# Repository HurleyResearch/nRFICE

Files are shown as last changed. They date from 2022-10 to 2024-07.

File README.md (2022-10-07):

# nRFICE
### nRF5340 with ICE40UP5K including JLink OB for instant BLE and FPGA development with zero dongles
In order to develop a number of comercial products, we (here at Hurley Research in Santa Cruz CA) needed a simple bluetooth 5 plus FPGA platform. nRFICE is meant to be a maximally simple solution for launching projects that require MCU plus FPGA and certainly if Bluetooth including mesh is needed.
### Arduino Uno compatibility
nRFICE is physically compatible with Arduino Uno shields, but take care that the GPIO level is 3.3V.
### JLink OB
Comercial eval/dev boards from chip manufactures, such as Nordic Semi, typically have the JLink debugger hardware embedded on the board for convenience. We have included JLink OB on nRFICE, allowing developers to get started without any additional hardare, programming dongles, etc. Out of box demos for both nRF5340 and ICE40UP5K can be loaded and debugged immediately with a single usb cable, or over BLE with the nRFICE android app.

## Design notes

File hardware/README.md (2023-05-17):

# nRFICE Hardware
Everything about the nRFICE PCB
- Eagle design files
- Gerbers
- Schematic
- Bill of matrials
- Pinout diagram

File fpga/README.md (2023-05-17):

# nRFICE Verilog Source
The nRFICE verilog source project is a simple RGB LED controller using PWM
- Bare bones hello world project for ICE40UP5K
- Built in Lattice Radiant IDE
## Getting started documentation will go here

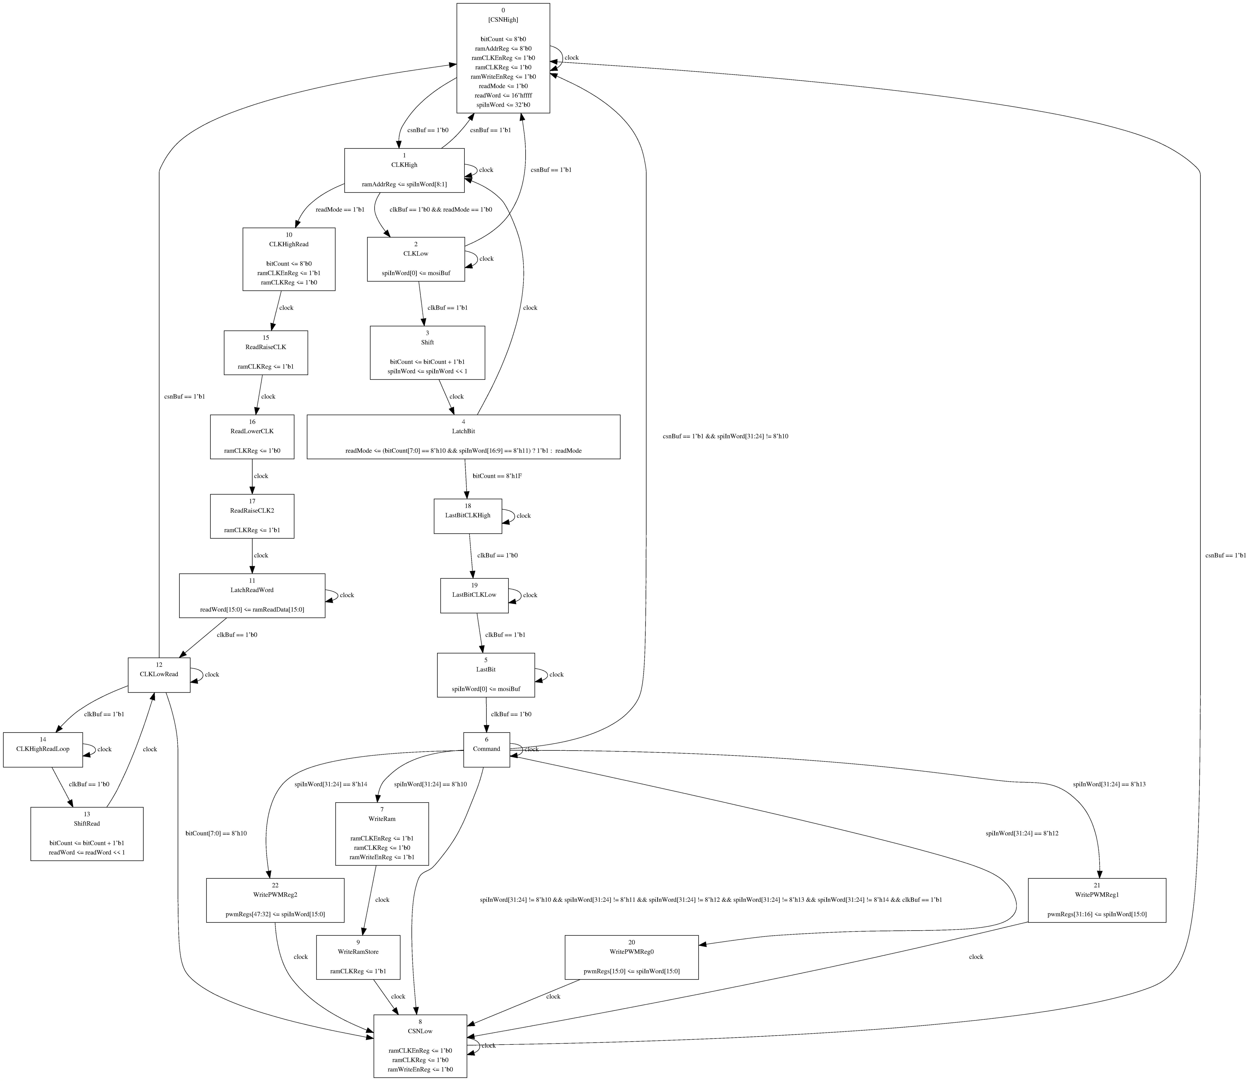
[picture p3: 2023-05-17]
fpga/work/spi.png

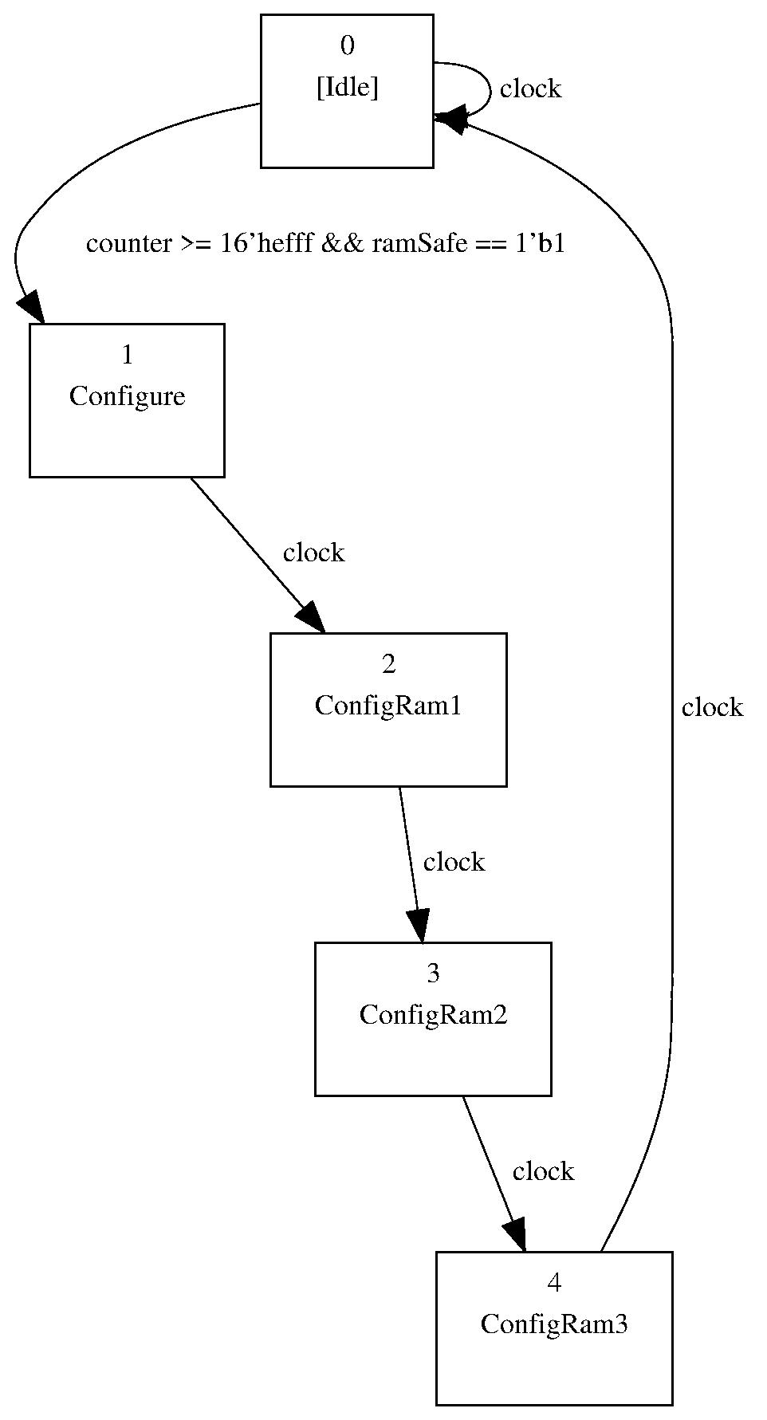
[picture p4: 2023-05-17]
fpga/work/pwm.png

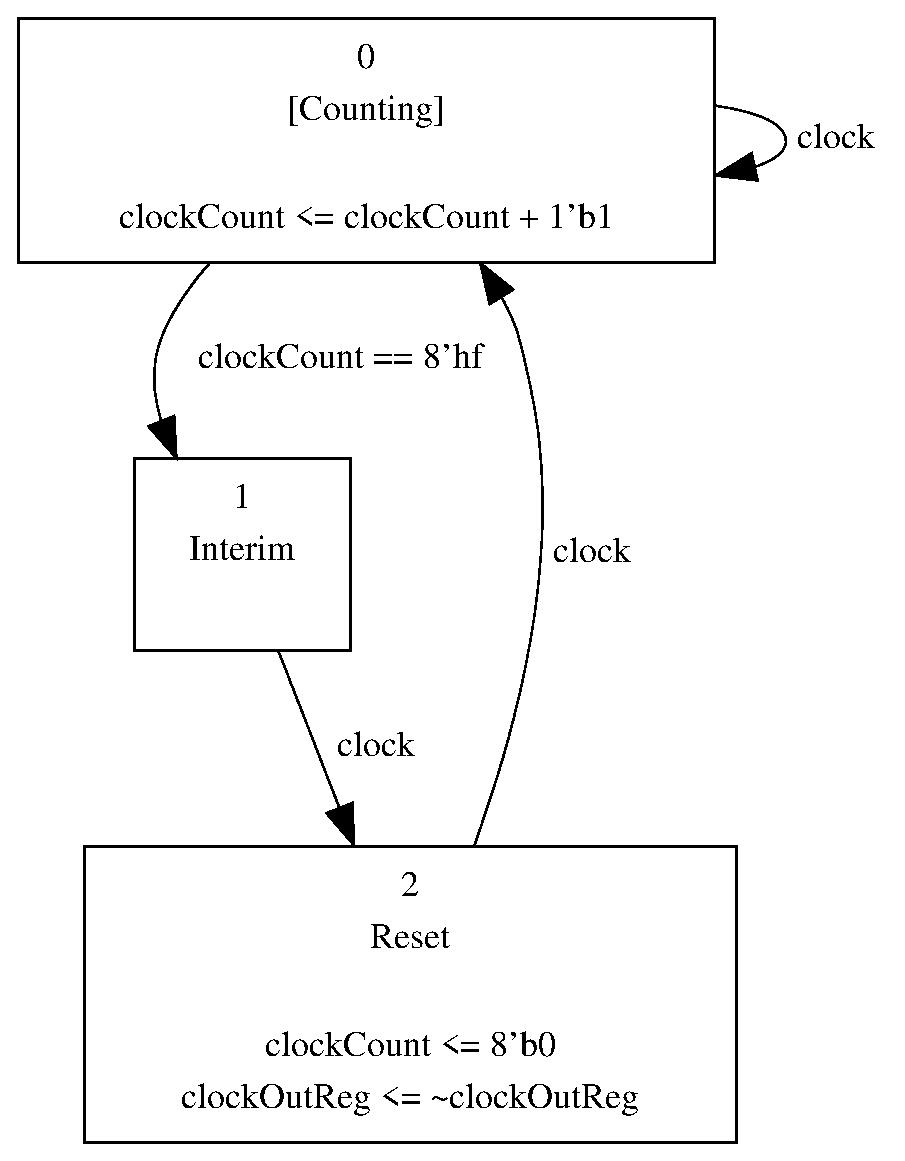
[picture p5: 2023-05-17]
fpga/work/clockstretch.png

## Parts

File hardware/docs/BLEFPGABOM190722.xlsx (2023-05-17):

Manufacturer | Manufacturer Part Number | Designator | Quantity | Description | Case | SMD BGA LLC(QFN) TH | Top/Bottom | points | Total points
BOOMELE | C30734 | J16, J9 | 2 | 2x8 pos 2.54mm female header | C30734 | TH | Top | 16 | 32
Adesto Technologies | AT25SF128A-SHB-T | U10 | 1 | NOR Flash 128 Mbit,2.7V to 3.6V,SOIC-W 208mil | AT25SF128A-SHB-T | SMD | Top | 8 | 8
BOOMELE | C40877 | J11 | 1 | 1x6 pos 2.54 female header | C40877 | TH | Top | 6 | 6
YAGEO | RC0402FR-075K1L | R19, R20, R21, R25 | 4 | 5.1K,1%,1/16W,0402 | RCL_R0402 | SMD | Top | 2 | 8
MICRONE | ME6211A33M3G-N | U3 | 1 | 500mA 3.3V SOT-23-3 LDO | ME6211A33M3G-N | SMD | Top | 3 | 3
MICRONE | ME6206A25XG | U6 | 1 | 300mA 2.5V SOT-23 LDO | ME6206A25XG | SMD | Top | 3 | 3
Samsung | CL05A105KP5NNNC | C11, C14, C15, C16, C17, C18, C19, C20, C21, C23, C5, C68, C71 | 13 | 1uF,10V,10%,X5R,0402 | RCL_C0402 | SMD | Top | 2 | 26
YAGEO | RC0402FR-07100RL | R22, R8, R91 | 3 | 100 Ohm,1%,1/16W,0402 | RCL_R0402 | SMD | Top | 2 | 6
YAGEO | RC0402FR-07220RL | R11 | 1 | 220 Ohm,1%,1/16W,0402 | RCL_R0402 | SMD | Top | 2 | 2
YAGEO | RC0402FR-070RL | R24, R38, R39 | 3 | 0 Ohm,1%,1/16W,0402 | RCL_R0402 | SMD | Top | 2 | 6
Murata | BLM15AG121SN1D | L1 | 1 | FERRITE BEAD 120 OHM 0402 1LN | L0402 | SMD | Top | 2 | 2
ST Micro | STM32F072CBU6TR | U8 | 1 | JLINK OB MCU | STM32F072CBU6TR | SMD | Top | 49 | 49
XFCN | PZ254V-11-04P | J14, J15, J17, J3 | 4 | 1x4 pos 2.54 male header | PZ254V-11-04P | TH | Top | 4 | 16
BOOMELE | C35445 | J5 | 1 | 1x10 pos 2.54 female header | C35445 | TH | Top | 10 | 10
Fanstel | BT40F | U2 | 1 | nRF5340 Module | BT40F | SMD | Top | 61 | 61
YAGEO | RC0402FR-07100KL | R17 | 1 | 100K Ohm,1%,1/16W,0402 | RCL_R0402 | SMD | Top | 2 | 2
YAGEO | RC0402FR-07470RL | R10 | 1 | 470 Ohm,1%,1/16W,0402 | RCL_R0402 | SMD | Top | 2 | 2
YAGEO | RC0402FR-0710KL | R13, R14, R15, R18, R26, R27, R28, R29, R30, R31, R32, R37, R9 | 13 | 10K Ohm,1%,1/16W,0402 | RCL_R0402 | SMD | Top | 2 | 26
HX | HX6306P122MR | U9 | 1 | 300mA 1.2V SOT-23 LDO | HX6306P122MR | SMD | Top | 3 | 3
HGSEMI | LM1085S-5.0 | U4 | 1 | 3A 5V TO-263-3 LDO | LM1085S-5.0 | SMD | Top | 4 | 4
Yuandi | TS-1091C-A8B3-D2 | S1, S6, S7, S8 | 4 | 4.5mm 7mm SMD Tactile Switch | TS-1091C-A8B3-D2 | SMD | Top | 3 | 12
Samsung | CL21A106KOQNNNE | C12, C13, C3, C4, C9 | 5 | 10uF,16V,10%,X5R,0805 | RCL_C0805 | SMD | Top | 2 | 10
YAGEO | RC0402FR-071KL | R1, R5 | 2 | 1K Ohm,1%,1/16W,0402 | RCL_R0402 | SMD | Top | 2 | 4
SAKRO | DC-050-2.0-B | J7 | 1 | DC Power Receptacle 2mm 6.4mm 2A 30V SMD | DC-050-2.0-B | SMD | Top | 4 | 4
KEMET | C0402C104K8RAC7867 | C32, C34, C48, C6, C62, C63, C65, C67, C7, C70, C75, C8 | 12 | 0.1uF,10V,10%,X7R,0402 | RCL_C0402 | SMD | Top | 2 | 24
BOOMELE | C57369 | J4 | 1 | 1x10 pos 2.54 male header | C57369 | TH | Top | 10 | 10
YAGEO | RC0402FR-07680RL | R2, R3, R6, R7 | 4 | 680 Ohms,1%,1/16W,0402 | RCL_R0402 | SMD | Top | 2 | 8
Samsung | CL21A226MAYNNNE | C22 | 1 | 22uF,25V,20%,X5R,0805 | RCL_C0805 | SMD | Top | 2 | 2
XINGLIGHT | XL-1608SYGC-06 | D5 | 1 | 25mA 38mcd 2.1V 2800K~3160K 575nm 120° 55mW 0603 LED | XL-1608SYGC-06 | SMD | Top | 2 | 2
Nexperia | PRTR5V0U2X | D2 | 1 | TVS DIODE 5.5VWM SOT143B | PRTR5V0U2X | SMD | Top | 4 | 4
DEALON | USB-TYPE-C-020 | J2, J8 | 2 | usb type c connector | USB-TYPE-C-020 | SMD | Top | 12 | 24
CreeLED | UHD1110-FKA-CL1A13R3Q1BBQFMF3 | U1, U5 | 2 | RGB LED 1.9V Red, 2.9V Green, 2.9V Blue 0404 | UHD1110-FKA | SMD | Top | 4 | 8
YAGEO | RC0603FR-071RL | R16, R34, R35, R36 | 4 | 1 Ohm,1%,1/10W,0603 | RCL_R0603 | SMD | Top | 2 | 8
KEMET | C0402C103J4RAC | C10, C31, C69 | 3 | 0.01uF,16V,5%,X7R,0402 | RCL_C0402 | SMD | Top | 2 | 6
Lattice | ICE40UP5K-SG48I | U7 | 1 | FPGA 48-VFQFN | ICE40UP5K-SG48I | SMD | Top | 48 | 48
YAGEO | RC0603FR-070RL | R12, R33 | 2 | 0 Ohm,1%,1/10W,0603 | RCL_R0603 | SMD | Top | 2 | 4
Epson | X1G004171004000 | OSC1 | 1 | 32MHz Oscillator | X1G004171004000 | SMD | Top | 4 | 4

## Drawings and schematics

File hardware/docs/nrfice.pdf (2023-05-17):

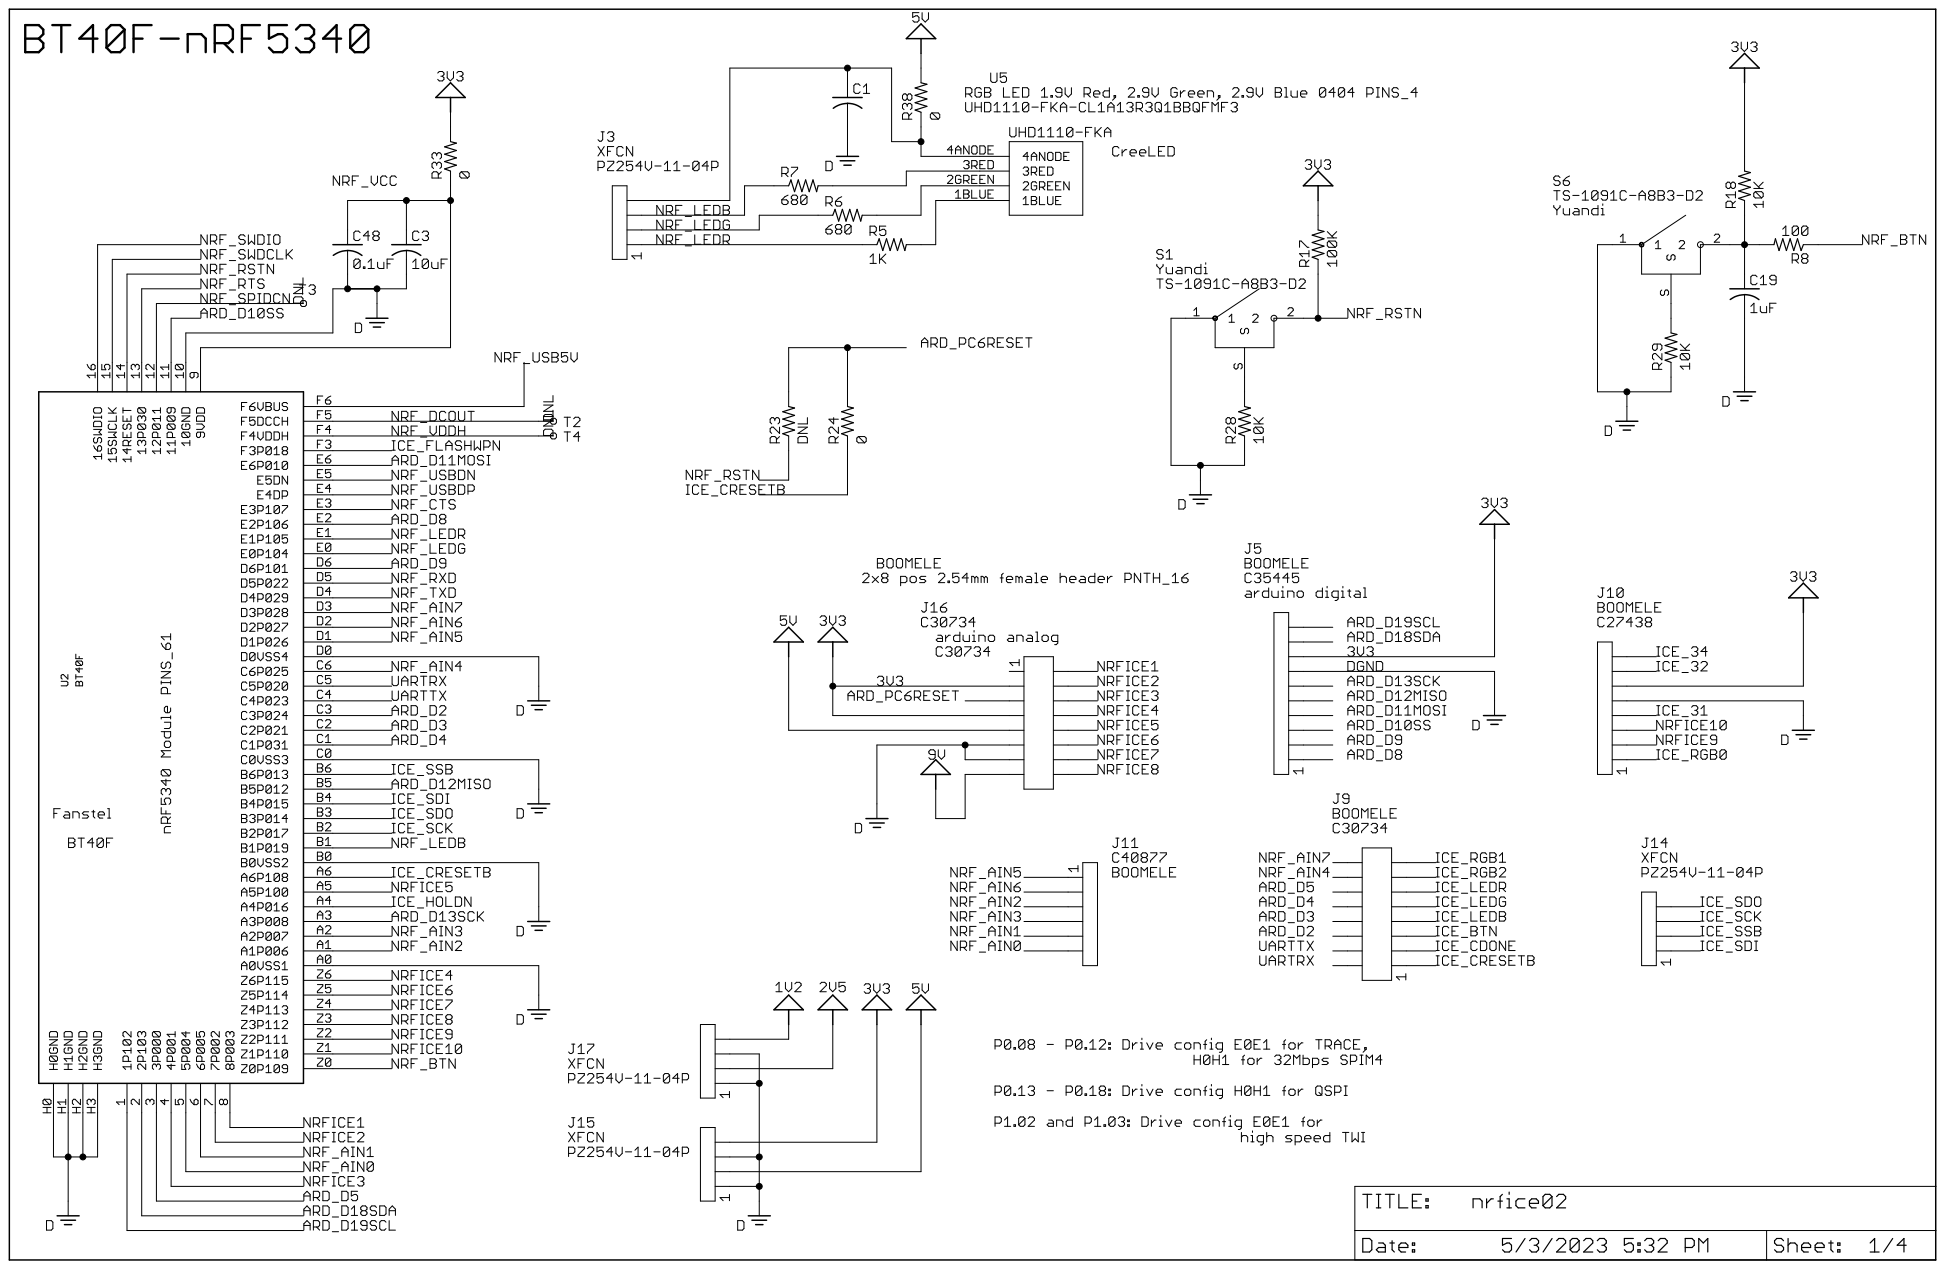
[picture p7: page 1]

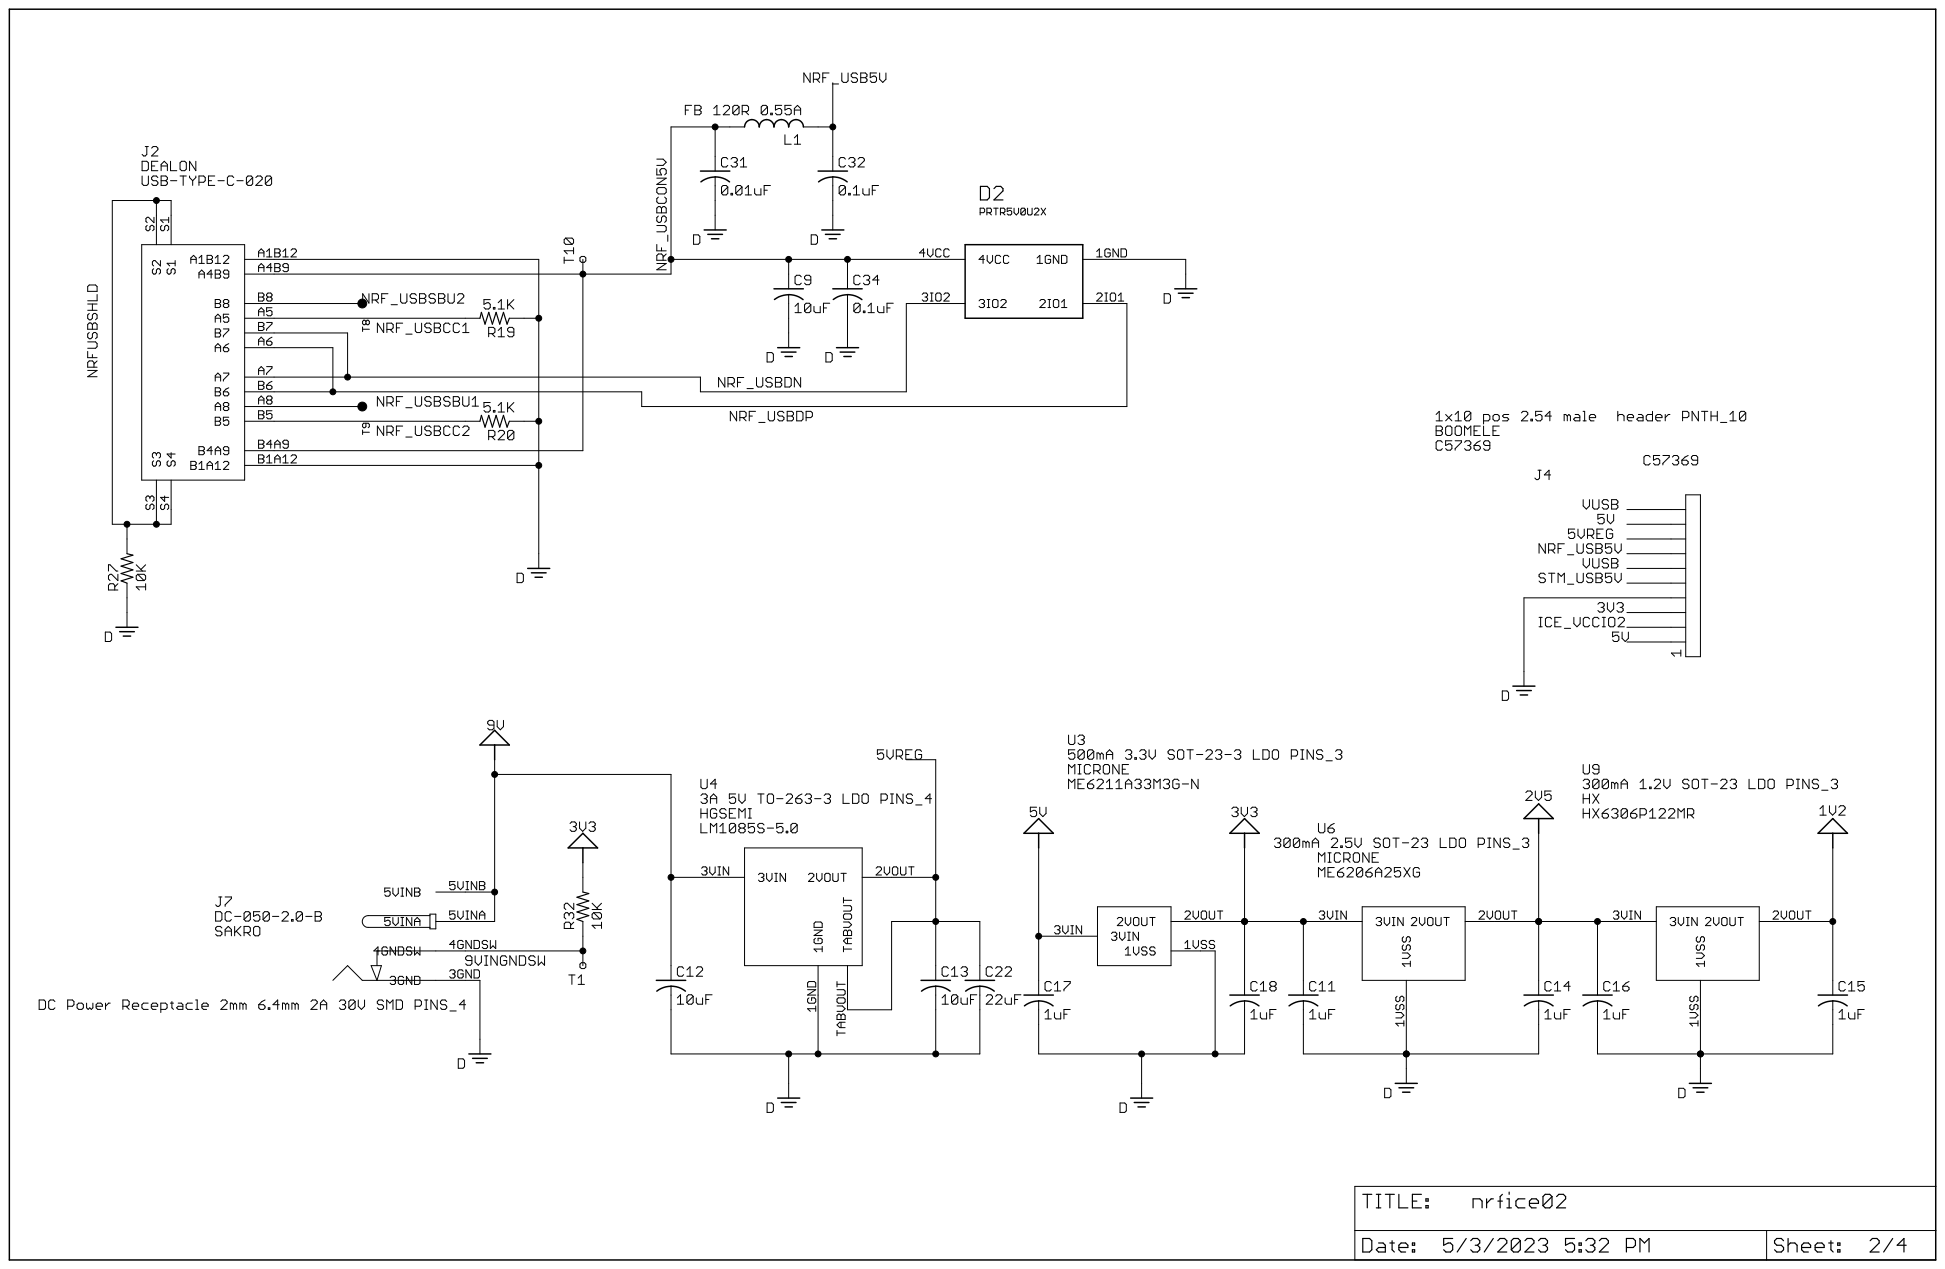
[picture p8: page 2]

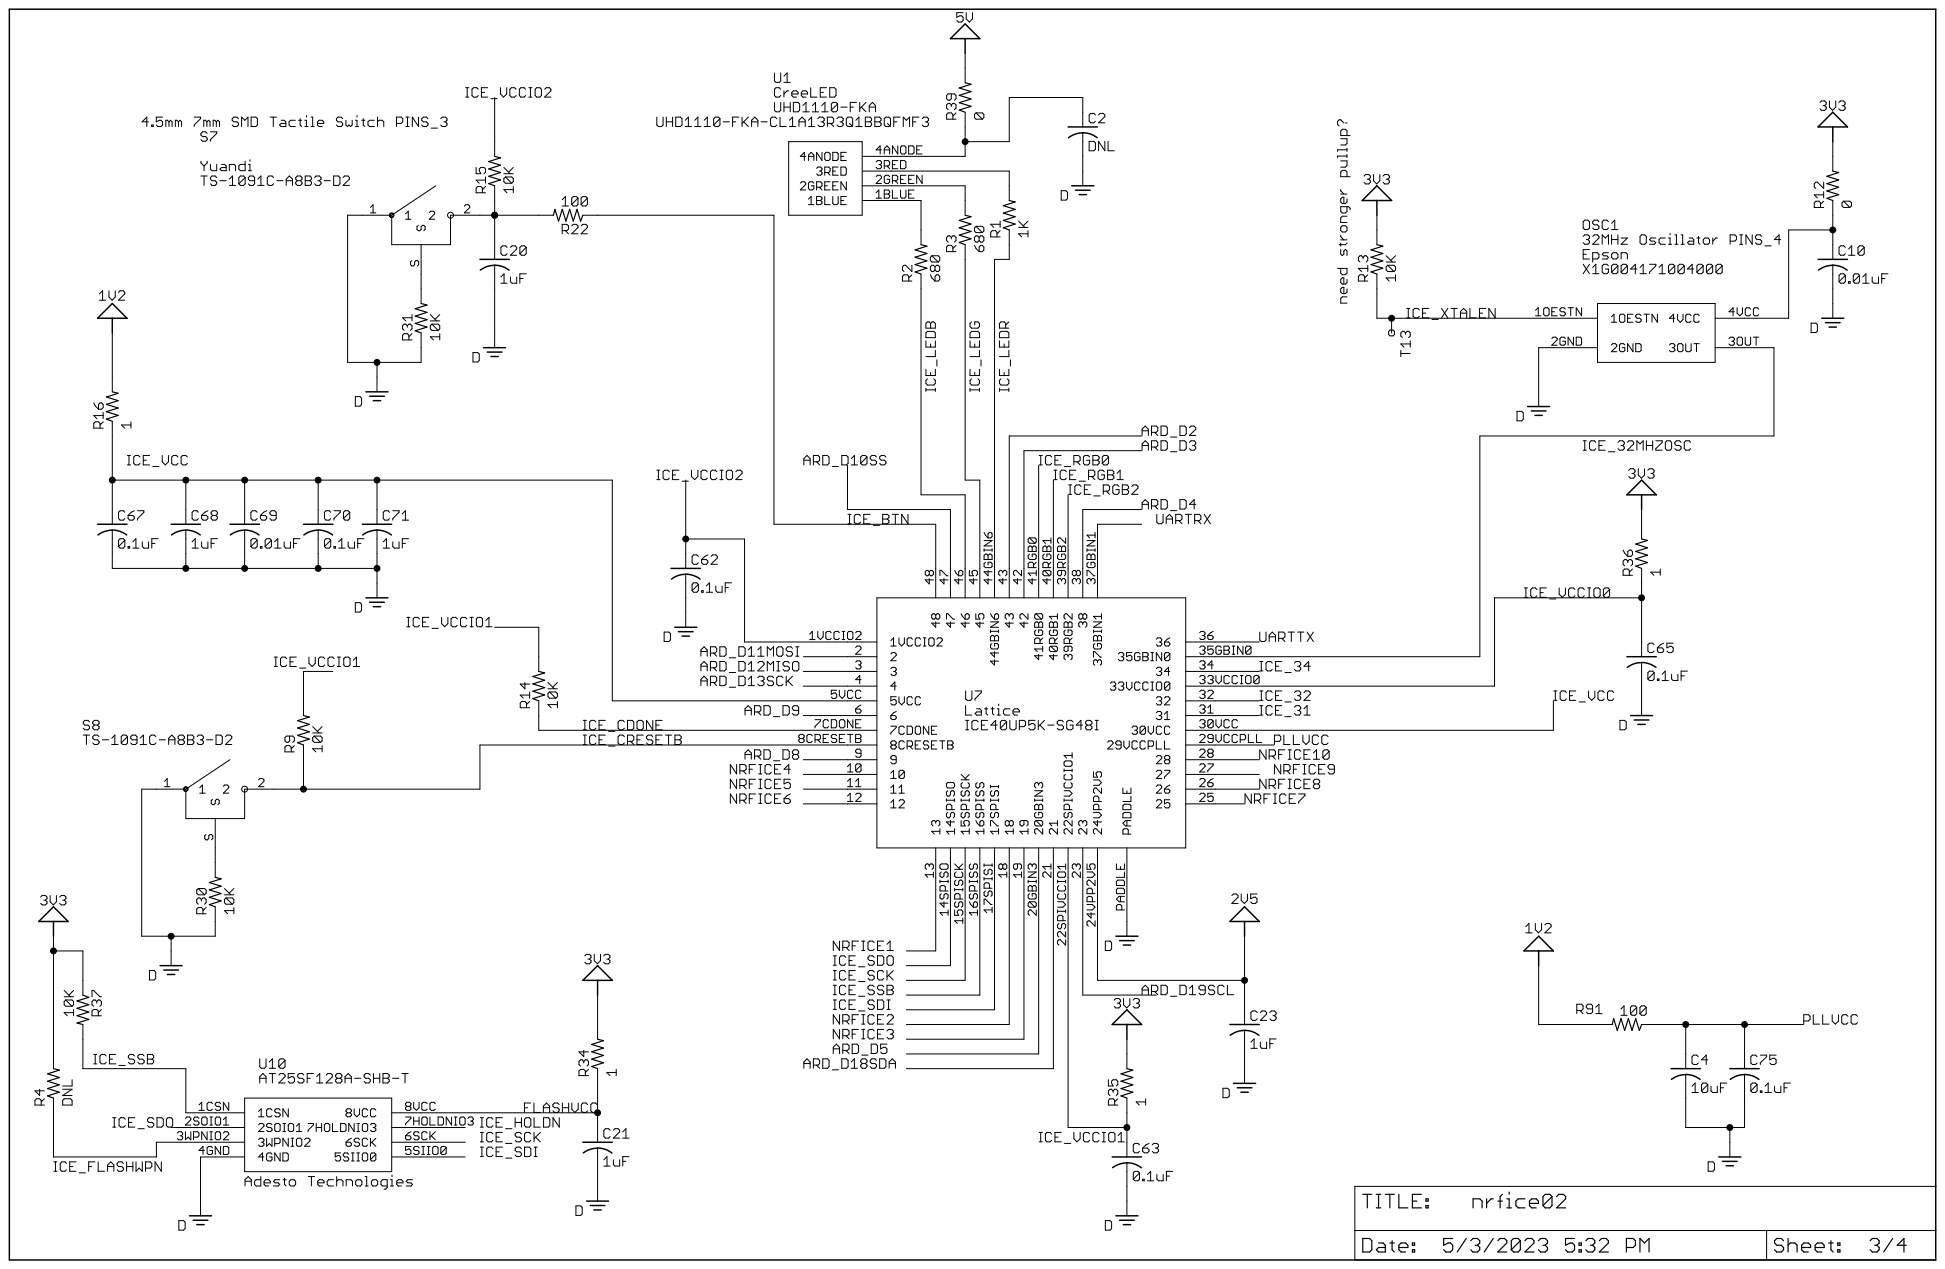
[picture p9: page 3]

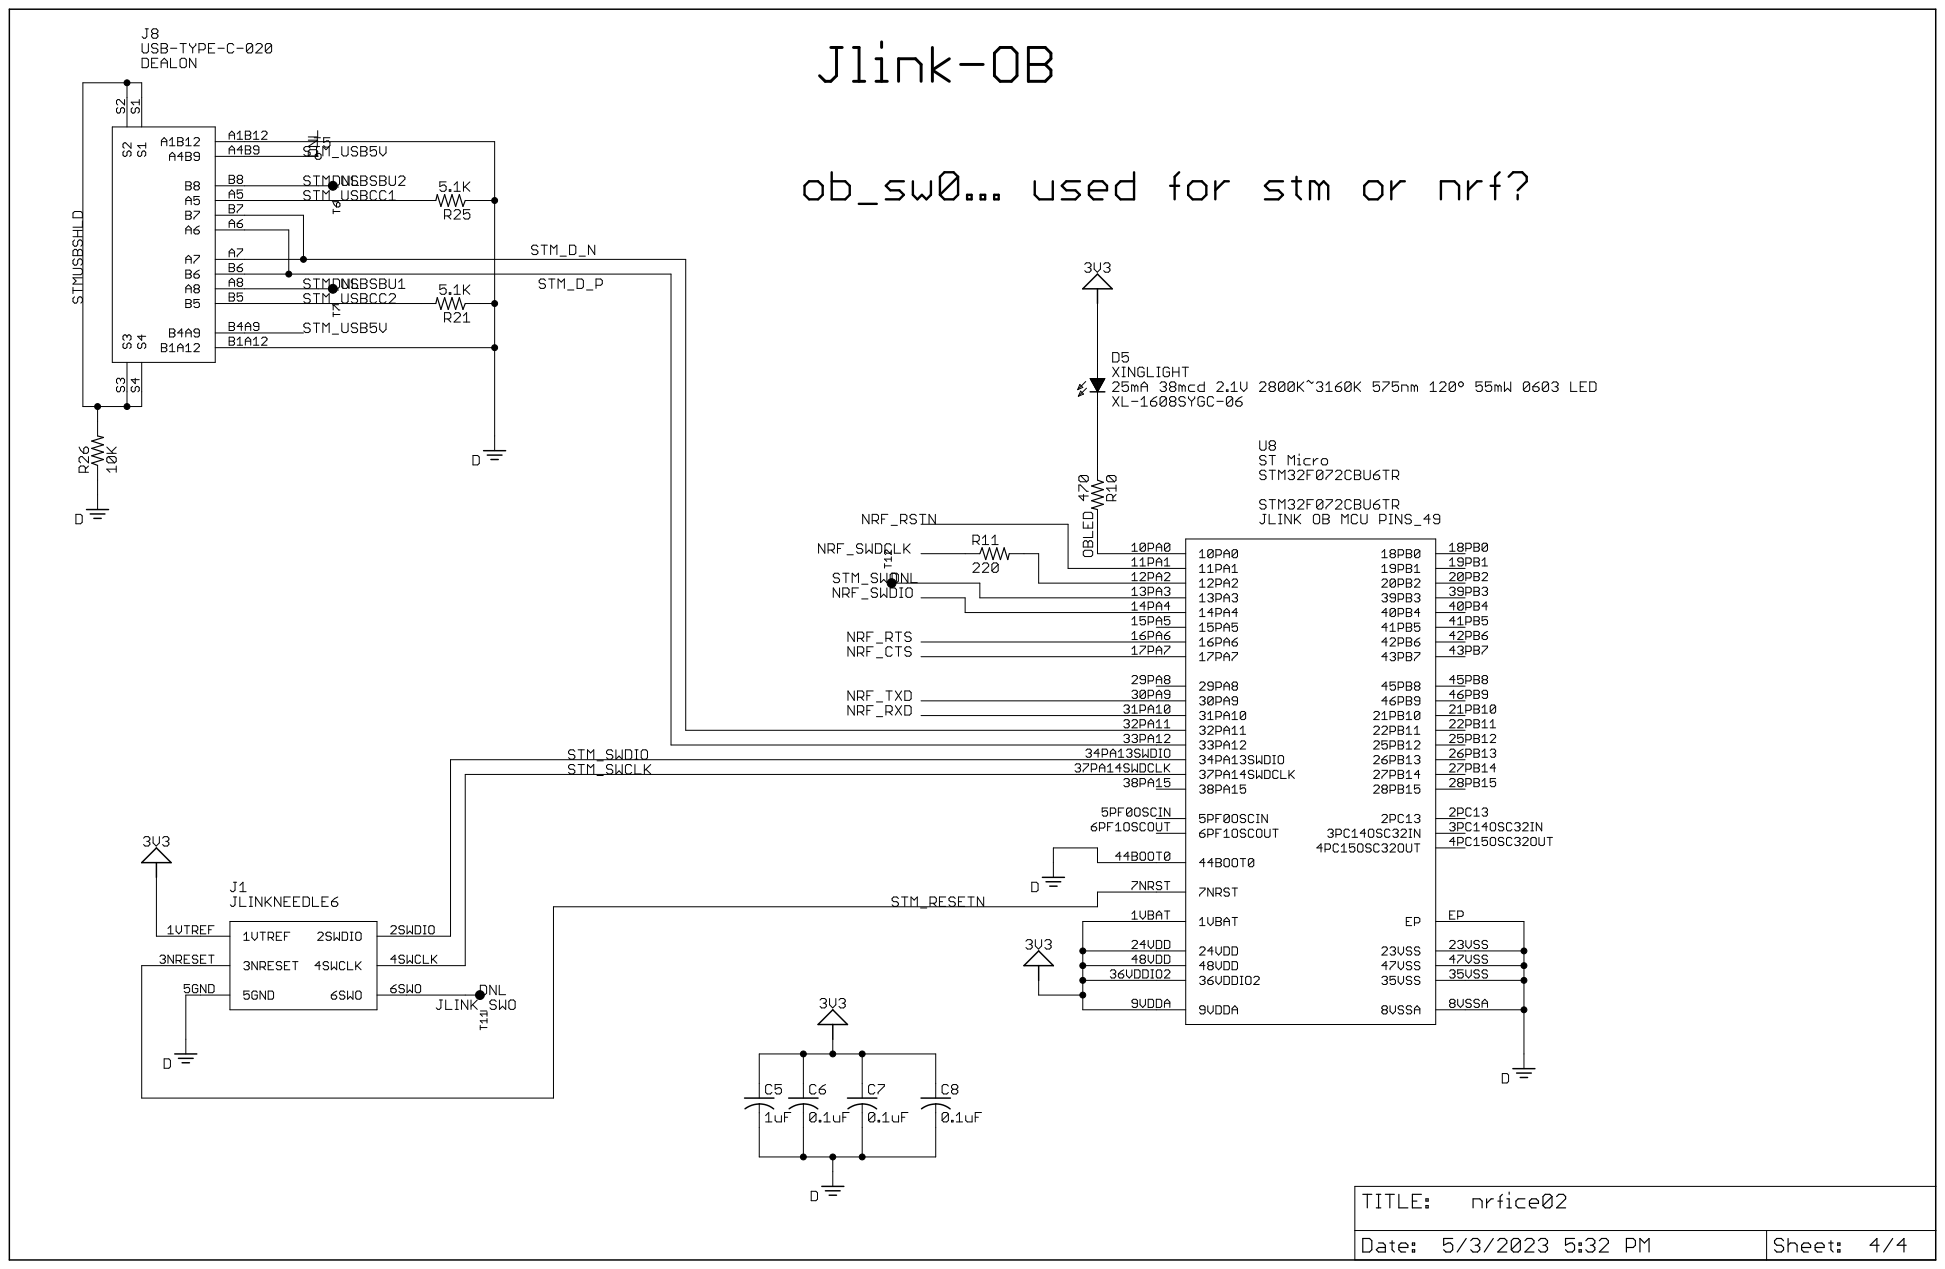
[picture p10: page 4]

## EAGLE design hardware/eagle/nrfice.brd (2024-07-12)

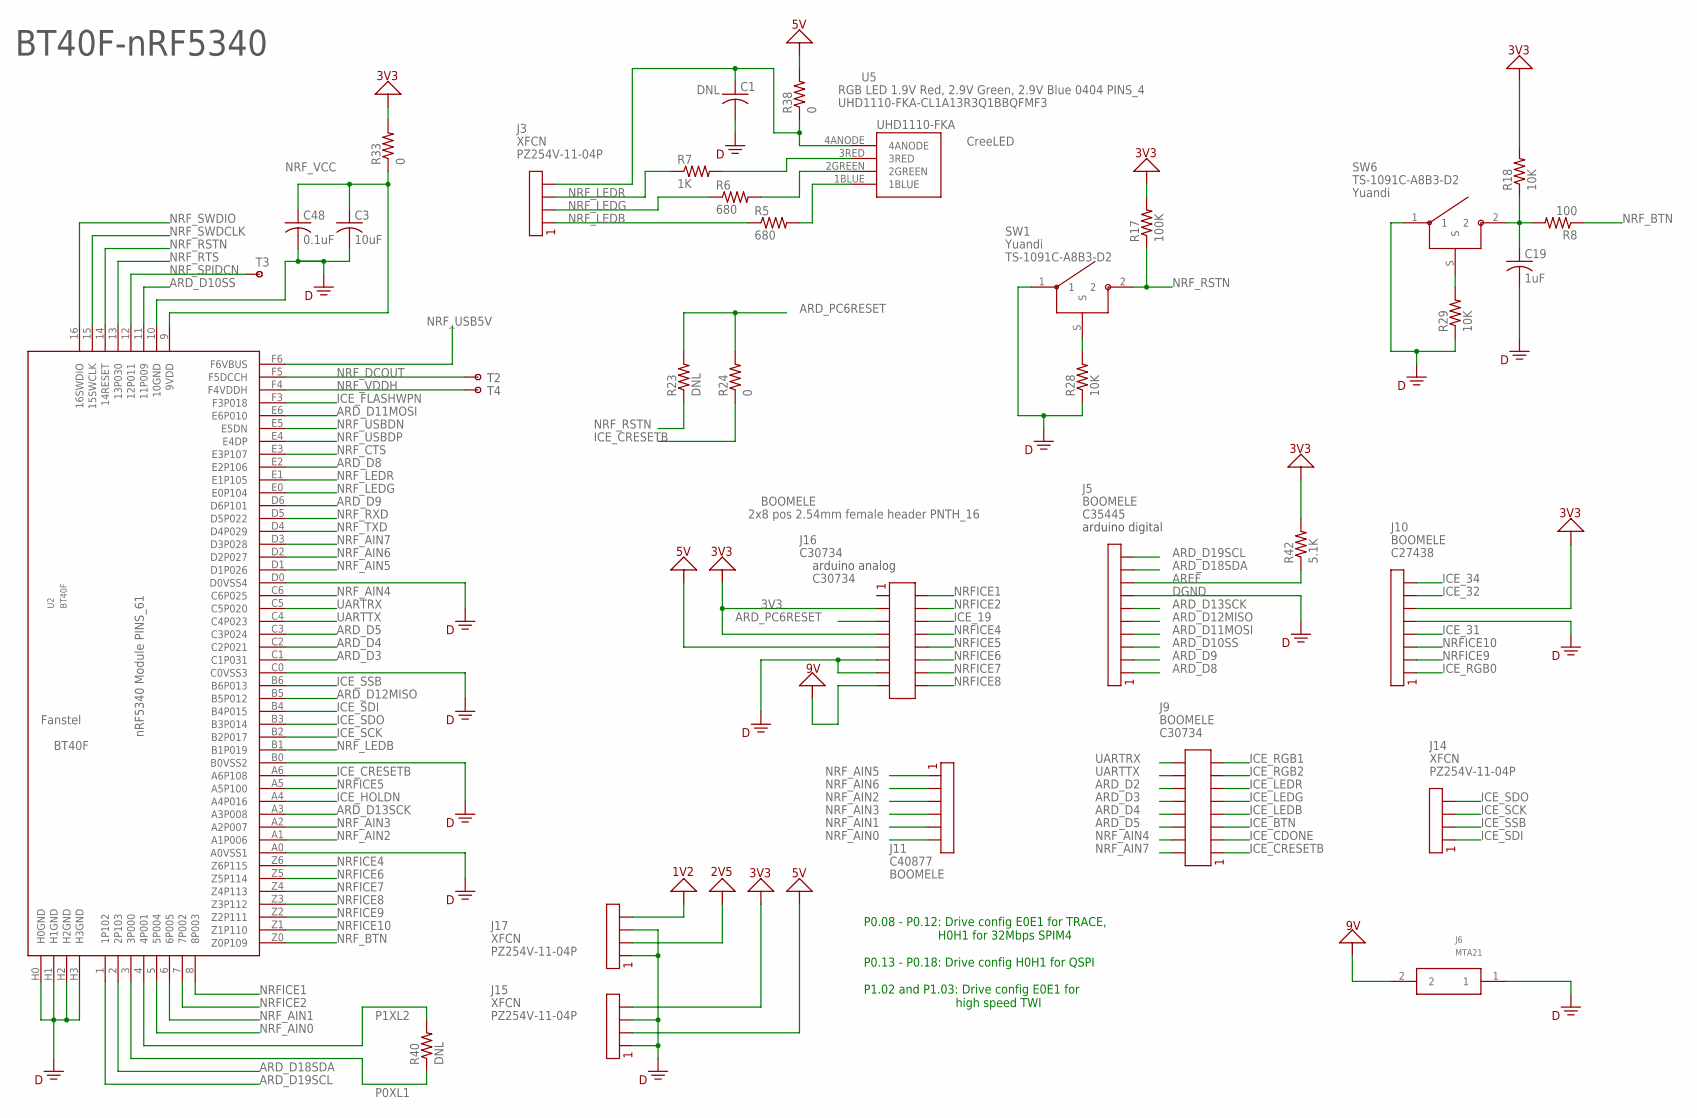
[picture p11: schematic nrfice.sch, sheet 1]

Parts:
C1: DNL; RCL_C0402; MPN CL05A105KP5NNNC
C3: 10uF; RCL_C0805; MPN CL21A106KOQNNNE
C19: 1uF; RCL_C0402; MPN CL05A105KP5NNNC
C48: 0.1uF; RCL_C0402; MPN C0402C104K8RAC7867
J3, J14, J15, J17: PZ254V-11-04P; MPN PZ254V-11-04P
J5: C35445; MPN C35445
J6: MTA21
J9, J16: C30734; MPN C30734
J10: C27438; MPN C27438
J11: C40877; MPN C40877
R5, R6: 680; RCL_R0402; MPN RC0402FR-07680RL
R7: 1K; RCL_R0402; MPN RC0402FR-071KL
R8: 100; RCL_R0402; MPN RC0402FR-07100RL
R17: 100K; RCL_R0402; MPN RC0402FR-07100KL
R18, R28, R29: 10K; RCL_R0402; MPN RC0402FR-0710KL
R23, R40: DNL; RCL_R0402; MPN RC0402FR-0710KL
R24, R38: 0; RCL_R0402; MPN RC0402FR-070RL
R33: 0; RCL_R0603; MPN RC0603FR-070RL
R42: 5.1K; RCL_R0402; MPN RC0402FR-075K1L
SW1, SW6: TS-1091C-A8B3-D2; MPN TS-1091C-A8B3-D2
T2, T3, T4: MTA1
U2: BT40F; MPN BT40F
U5: UHD1110-FKA; MPN UHD1110-FKA-CL1A13R3Q1BBQFMF3

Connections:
1V2: J17.4; also elsewhere on the board
2V5: J17.2; also elsewhere on the board
3V3: J10.6, J15.4, J16.3, J16.7, R17.2, R18.2, R33.2, R42.2; also elsewhere on the board
5V: J15.2, J16.9, R38.2; also elsewhere on the board
9V: J6.2, J16.15; also elsewhere on the board
ARD_D2: J9.12; also elsewhere on the board
ARD_D3: J9.10, U2.C1 (C1P031); also elsewhere on the board
ARD_D4: J9.8, U2.C2 (C2P021); also elsewhere on the board
ARD_D5: J9.6, U2.C3 (C3P024); also elsewhere on the board
ARD_D8: J5.1, U2.E2 (E2P106); also elsewhere on the board
ARD_D9: J5.2, U2.D6 (D6P101); also elsewhere on the board
ARD_D10SS: J5.3, U2.11 (11P009); also elsewhere on the board
ARD_D11MOSI: J5.4, U2.E6 (E6P010); also elsewhere on the board
ARD_D12MISO: J5.5, U2.B5 (B5P012); also elsewhere on the board
ARD_D13SCK: J5.6, U2.A3 (A3P008); also elsewhere on the board
ARD_D18SDA: J5.9, U2.2 (2P103); also elsewhere on the board
ARD_D19SCL: J5.10, U2.1 (1P102); also elsewhere on the board
ARD_PC6RESET: J16.5, R23.2, R24.2
AREF: J5.8, R42.1
DGND: C1.2, C3.2, C19.2, C48.2, J5.7, J6.1, J10.5, J15.1, J15.3, J16.11, J16.13, J17.1, J17.3, R28.1, R29.1, SW1.1, SW6.1, U2.10 (10GND), U2.A0 (A0VSS1), U2.B0 (B0VSS2), U2.C0 (C0VSS3), U2.D0 (D0VSS4), U2.H0 (H0GND), U2.H1 (H1GND), U2.H2 (H2GND), U2.H3 (H3GND); also elsewhere on the board
ICE_19: J16.6; also elsewhere on the board
ICE_31: J10.4; also elsewhere on the board
ICE_32: J10.7; also elsewhere on the board
ICE_34: J10.8; also elsewhere on the board
ICE_BTN: J9.5; also elsewhere on the board
ICE_CDONE: J9.3; also elsewhere on the board
ICE_CRESETB: J9.1, R24.1, U2.A6 (A6P108); also elsewhere on the board
ICE_FLASHWPN: U2.F3 (F3P018); also elsewhere on the board
ICE_HOLDN: U2.A4 (A4P016); also elsewhere on the board
ICE_LEDB: J9.7; also elsewhere on the board
ICE_LEDG: J9.9; also elsewhere on the board
ICE_LEDR: J9.11; also elsewhere on the board
ICE_RGB0: J10.1; also elsewhere on the board
ICE_RGB1: J9.15; also elsewhere on the board
ICE_RGB2: J9.13; also elsewhere on the board
ICE_SCK: J14.3, U2.B2 (B2P017); also elsewhere on the board
ICE_SDI: J14.1, U2.B4 (B4P015); also elsewhere on the board
ICE_SDO: J14.4, U2.B3 (B3P014); also elsewhere on the board
ICE_SSB: J14.2, U2.B6 (B6P013); also elsewhere on the board
unnamed: R5.2, U5.1BLUE
unnamed: R6.2, U5.2GREEN
unnamed: R7.2, U5.3RED
unnamed: C19.1, R8.2, R18.1, SW6.2
unnamed: R28.2, SW1.S
unnamed: R29.2, SW6.S
unnamed: C1.1, J3.4, R38.1, U5.4ANODE
NRFICE1: J16.2, U2.8 (8P003); also elsewhere on the board
NRFICE2: J16.4, U2.7 (7P002); also elsewhere on the board
NRFICE4: J16.8, U2.Z6 (Z6P115); also elsewhere on the board
NRFICE5: J16.10, U2.A5 (A5P100); also elsewhere on the board
NRFICE6: J16.12, U2.Z5 (Z5P114); also elsewhere on the board
NRFICE7: J16.14, U2.Z4 (Z4P113); also elsewhere on the board
NRFICE8: J16.16, U2.Z3 (Z3P112); also elsewhere on the board
NRFICE9: J10.2, U2.Z2 (Z2P111); also elsewhere on the board
NRFICE10: J10.3, U2.Z1 (Z1P110); also elsewhere on the board
NRF_AIN0: J11.6, U2.5 (5P004)
NRF_AIN1: J11.5, U2.6 (6P005)
NRF_AIN2: J11.3, U2.A1 (A1P006)
NRF_AIN3: J11.4, U2.A2 (A2P007)
NRF_AIN4: J9.4, U2.C6 (C6P025)
NRF_AIN5: J11.1, U2.D1 (D1P026)
NRF_AIN6: J11.2, U2.D2 (D2P027)
NRF_AIN7: J9.2, U2.D3 (D3P028)
NRF_BTN: R8.1, U2.Z0 (Z0P109)
NRF_CTS: U2.E3 (E3P107); also elsewhere on the board
NRF_DCOUT: T2.1, U2.F5 (F5DCCH)
NRF_LEDB: J3.1, R5.1, U2.B1 (B1P019)
NRF_LEDG: J3.2, R6.1, U2.E0 (E0P104)
NRF_LEDR: J3.3, R7.1, U2.E1 (E1P105)
NRF_RSTN: R17.1, R23.1, SW1.2, U2.14 (14RESET); also elsewhere on the board
NRF_RTS: U2.13 (13P030); also elsewhere on the board
NRF_RXD: U2.D5 (D5P022); also elsewhere on the board
NRF_SPIDCN: T3.1, U2.12 (12P011)
NRF_SWDCLK: U2.15 (15SWCLK); also elsewhere on the board
NRF_SWDIO: U2.16 (16SWDIO); also elsewhere on the board
NRF_TXD: U2.D4 (D4P029); also elsewhere on the board
NRF_USB5V: U2.F6 (F6VBUS); also elsewhere on the board
NRF_USBDN: U2.E5 (E5DN); also elsewhere on the board
NRF_USBDP: U2.E4 (E4DP); also elsewhere on the board
NRF_VCC: C3.1, C48.1, R33.1, U2.9 (9VDD)
NRF_VDDH: T4.1, U2.F4 (F4VDDH)
P0XL1: R40.1, U2.3 (3P000)
P1XL2: R40.2, U2.4 (4P001)
UARTRX: J9.16, U2.C5 (C5P020); also elsewhere on the board
UARTTX: J9.14, U2.C4 (C4P023); also elsewhere on the board

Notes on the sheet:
BT40F-nRF5340
arduino analog
arduino digital
P0.08 - P0.12: Drive config E0E1 for TRACE, H0H1 for 32Mbps SPIM4 P0.13 - P0.18: Drive config H0H1 for QSPI P1.02 and P1.03: Drive config E0E1 for high speed TWI

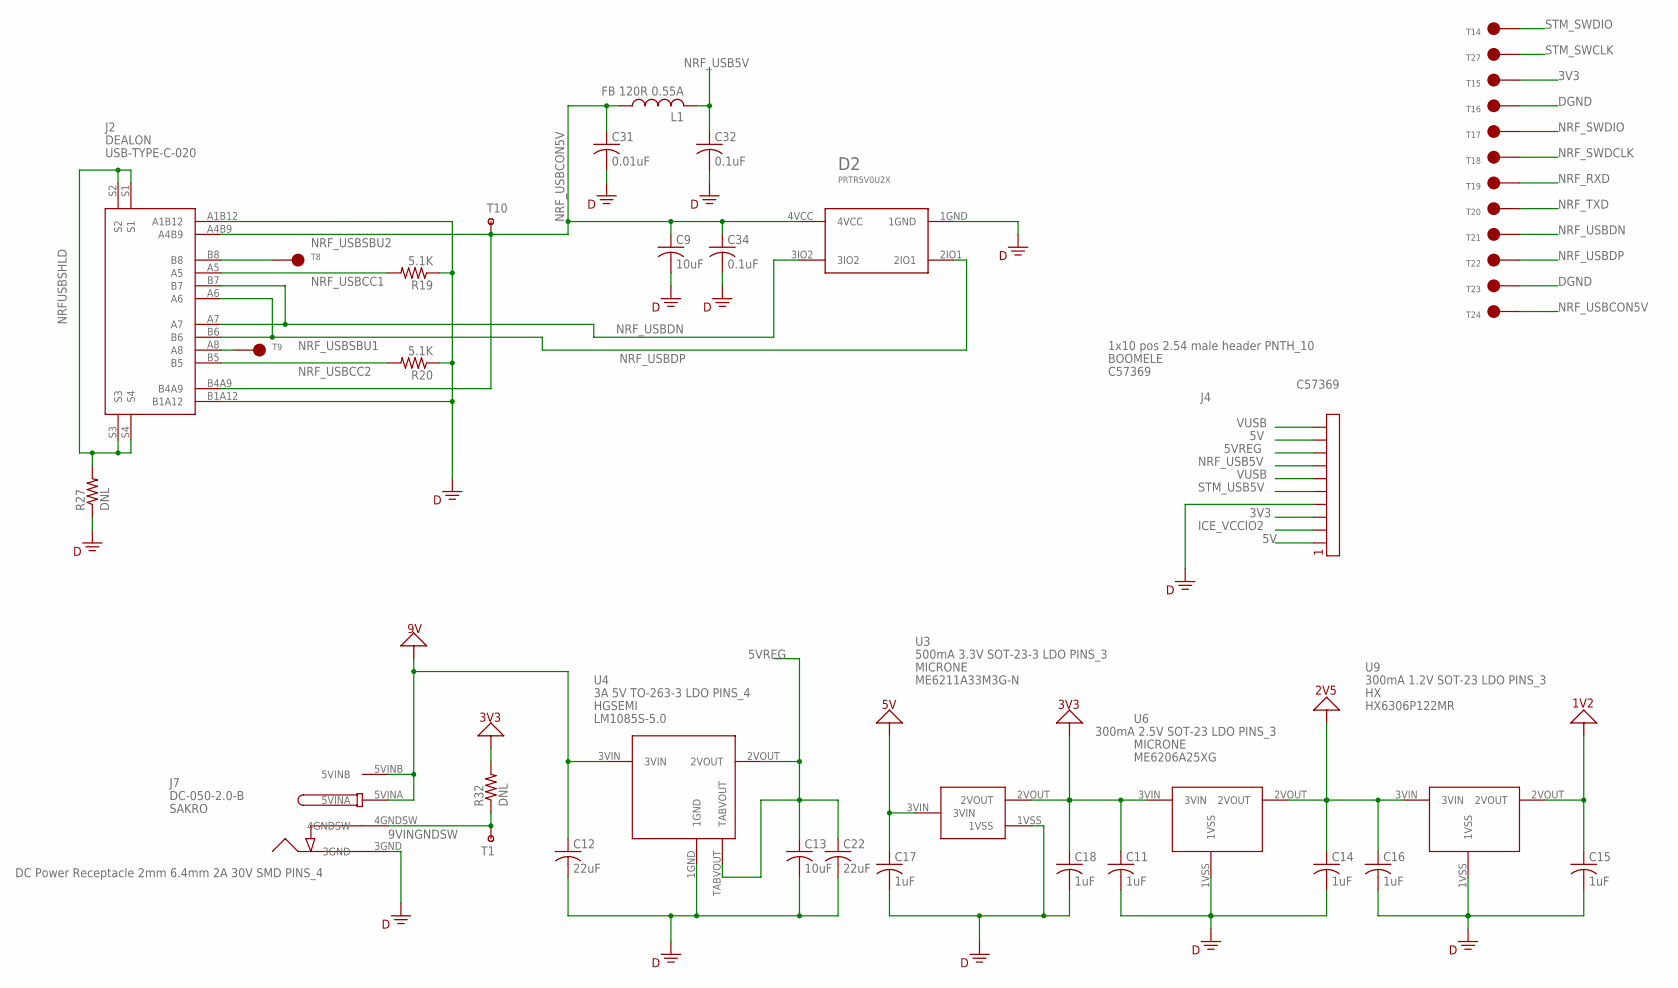
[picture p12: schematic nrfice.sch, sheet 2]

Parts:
C9, C13: 10uF; RCL_C0805; MPN CL21A106KOQNNNE
C11, C14, C15, C16, C17, C18: 1uF; RCL_C0402; MPN CL05A105KP5NNNC
C12, C22: 22uF; RCL_C0805; MPN CL21A226MAYNNNE
C31: 0.01uF; RCL_C0402; MPN C0402C103J4RAC
C32, C34: 0.1uF; RCL_C0402; MPN C0402C104K8RAC7867
D2: PRTR5V0U2X; MPN PRTR5V0U2X
J2: USB-TYPE-C-020; MPN USB-TYPE-C-020
J4: C57369; MPN C57369
J7: DC-050-2.0-B; MPN DC-050-2.0-B
L1: FB 120R 0.55A; L0402; MPN BLM15AG121SN1D
R19, R20: 5.1K; RCL_R0402; MPN RC0402FR-075K1L
R27, R32: DNL; RCL_R0402; MPN RC0402FR-0710KL
T1, T10: MTA1
T8, T9: T
T14, T15, T16, T17, T18, T19, T20, T21, T22, T23, T24, T27: TT2; T2
U3: ME6211A33M3G-N; MPN ME6211A33M3G-N
U4: LM1085S-5.0; MPN LM1085S-5.0
U6: ME6206A25XG; MPN ME6206A25XG
U9: HX6306P122MR; MPN HX6306P122MR

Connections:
1V2: C15.1, U9.2VOUT; also elsewhere on the board
2V5: C14.1, C16.1, U6.2VOUT, U9.3VIN; also elsewhere on the board
3V3: C11.1, C18.1, J4.3, R32.2, T15.T, U3.2VOUT, U6.3VIN; also elsewhere on the board
5V: C17.1, J4.1, J4.9, U3.3VIN; also elsewhere on the board
5VREG: C13.1, C22.1, J4.8, U4.2VOUT, U4.TABVOUT
9V: C12.1, J7.5VINA, J7.5VINB, U4.3VIN; also elsewhere on the board
9VINGNDSW: J7.4GNDSW, R32.1, T1.1
DGND: C9.2, C11.2, C12.2, C13.2, C14.2, C15.2, C16.2, C17.2, C18.2, C22.2, C31.2, C32.2, C34.2, D2.1GND, J2.A1B12, J2.B1A12, J4.4, J7.3GND, R19.1, R20.1, R27.1, T16.T, T23.T, U3.1VSS, U4.1GND, U6.1VSS, U9.1VSS; also elsewhere on the board
ICE_VCCIO2: J4.2; also elsewhere on the board
NRFUSBSHLD: J2.S1, J2.S2, J2.S3, J2.S4, R27.2
NRF_RXD: T19.T; also elsewhere on the board
NRF_SWDCLK: T18.T; also elsewhere on the board
NRF_SWDIO: T17.T; also elsewhere on the board
NRF_TXD: T20.T; also elsewhere on the board
NRF_USB5V: C32.1, J4.7, L1.2; also elsewhere on the board
NRF_USBCC1: J2.A5, R19.2
NRF_USBCC2: J2.B5, R20.2
NRF_USBCON5V: C9.1, C31.1, C34.1, D2.4VCC, J2.A4B9, J2.B4A9, L1.1, T10.1, T24.T
NRF_USBDN: D2.3IO2, J2.A7, J2.B7, T21.T; also elsewhere on the board
NRF_USBDP: D2.2IO1, J2.A6, J2.B6, T22.T; also elsewhere on the board
NRF_USBSBU1: J2.A8, T9.T
NRF_USBSBU2: J2.B8, T8.T
STM_SWCLK: T27.T; also elsewhere on the board
STM_SWDIO: T14.T; also elsewhere on the board
STM_USB5V: J4.5; also elsewhere on the board
VUSB: J4.6, J4.10

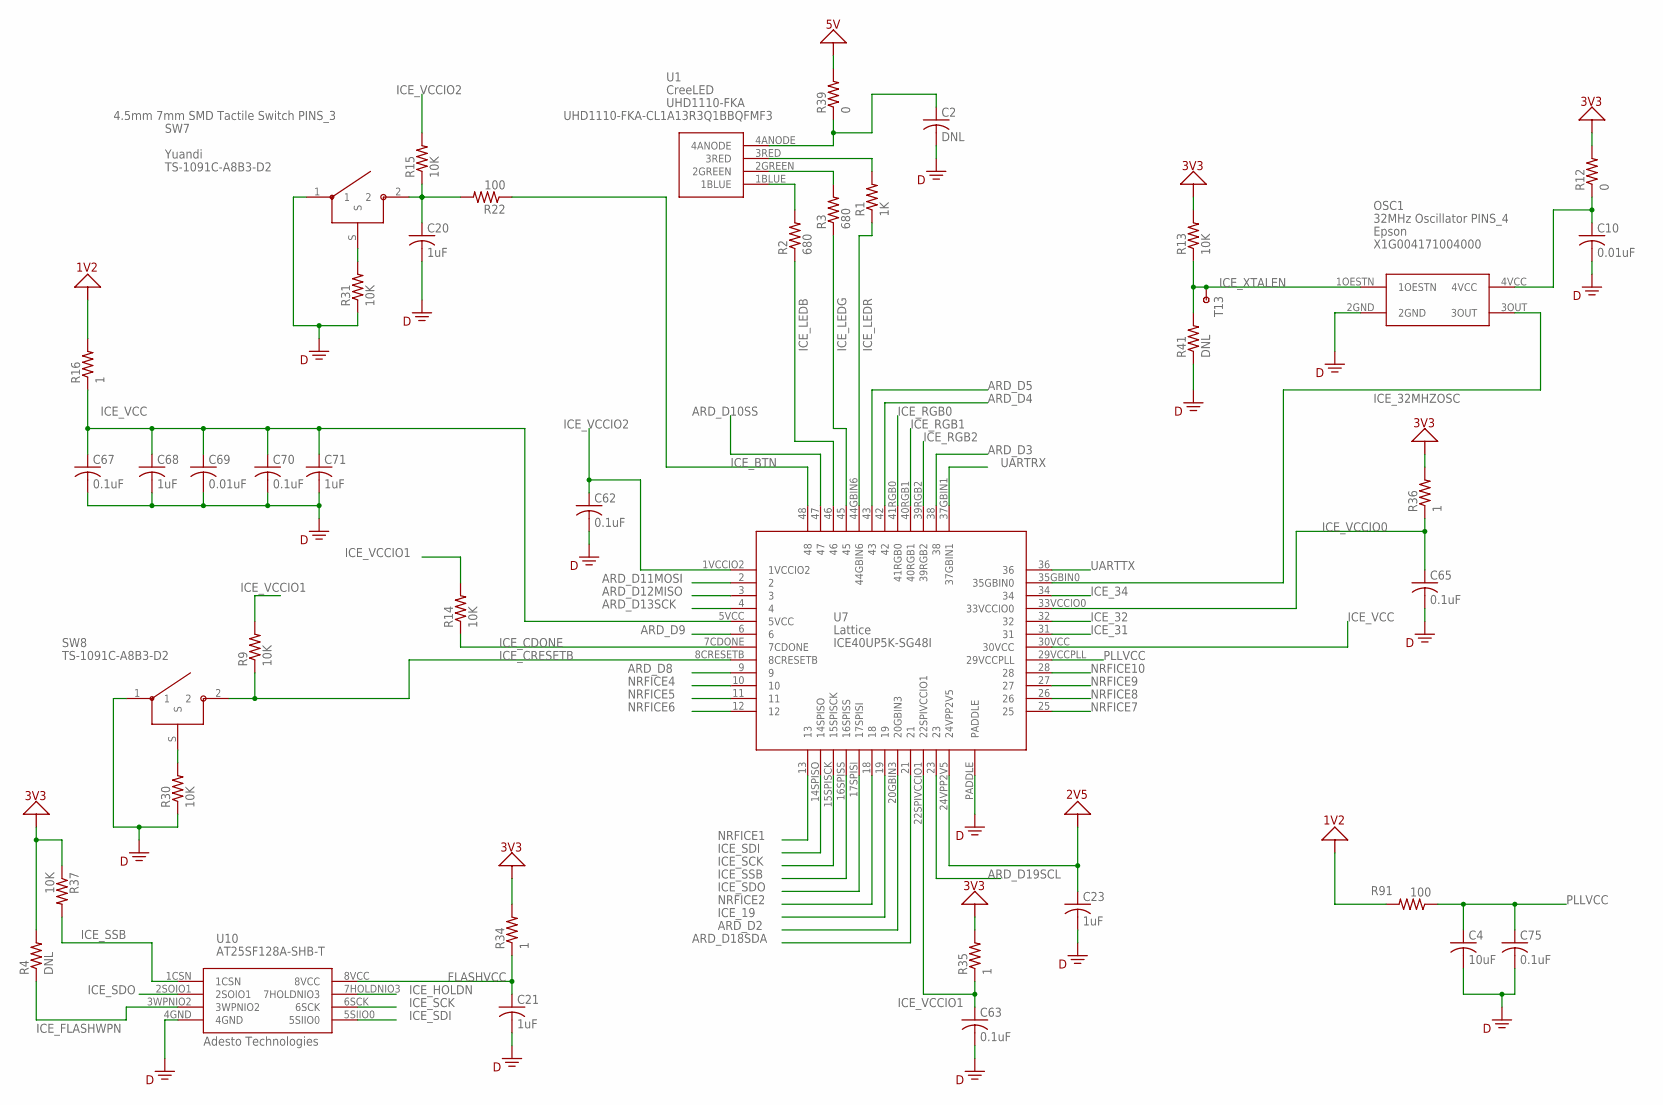
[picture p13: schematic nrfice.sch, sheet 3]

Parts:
C2: DNL; RCL_C0402; MPN CL05A105KP5NNNC
C4: 10uF; RCL_C0805; MPN CL21A106KOQNNNE
C10, C69: 0.01uF; RCL_C0402; MPN C0402C103J4RAC
C20, C21, C23, C68, C71: 1uF; RCL_C0402; MPN CL05A105KP5NNNC
C62, C63, C65, C67, C70, C75: 0.1uF; RCL_C0402; MPN C0402C104K8RAC7867
OSC1: X1G004171004000; MPN X1G004171004000
R1: 1K; RCL_R0402; MPN RC0402FR-071KL
R2, R3: 680; RCL_R0402; MPN RC0402FR-07680RL
R4, R41: DNL; RCL_R0402; MPN RC0402FR-0710KL
R9, R13, R14, R15, R30, R31, R37: 10K; RCL_R0402; MPN RC0402FR-0710KL
R12: 0; RCL_R0603; MPN RC0603FR-070RL
R16, R34, R35, R36: 1; RCL_R0603; MPN RC0603FR-071RL
R22, R91: 100; RCL_R0402; MPN RC0402FR-07100RL
R39: 0; RCL_R0402; MPN RC0402FR-070RL
SW7, SW8: TS-1091C-A8B3-D2; MPN TS-1091C-A8B3-D2
T13: MTA1
U1: UHD1110-FKA; MPN UHD1110-FKA-CL1A13R3Q1BBQFMF3
U7: ICE40UP5K-SG48I; MPN ICE40UP5K-SG48I
U10: AT25SF128A-SHB-T; MPN AT25SF128A-SHB-T

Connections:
1V2: R16.2, R91.2; also elsewhere on the board
2V5: C23.1, U7.24VPP2V5; also elsewhere on the board
3V3: R4.2, R12.2, R13.2, R34.2, R35.2, R36.2, R37.1; also elsewhere on the board
5V: R39.2; also elsewhere on the board
ARD_D2: U7.20GBIN3; also elsewhere on the board
ARD_D3: U7.38; also elsewhere on the board
ARD_D4: U7.42; also elsewhere on the board
ARD_D5: U7.43; also elsewhere on the board
ARD_D8: U7.9; also elsewhere on the board
ARD_D9: U7.6; also elsewhere on the board
ARD_D10SS: U7.47; also elsewhere on the board
ARD_D11MOSI: U7.2; also elsewhere on the board
ARD_D12MISO: U7.3; also elsewhere on the board
ARD_D13SCK: U7.4; also elsewhere on the board
ARD_D18SDA: U7.21; also elsewhere on the board
ARD_D19SCL: U7.23; also elsewhere on the board
DGND: C2.2, C4.2, C10.2, C20.2, C21.2, C23.2, C62.2, C63.2, C65.2, C67.2, C68.2, C69.2, C70.2, C71.2, C75.2, OSC1.2GND, R30.1, R31.1, R41.1, SW7.1, SW8.1, U7.PADDLE, U10.4GND; also elsewhere on the board
FLASHVCC: C21.1, R34.1, U10.8VCC
ICE_19: U7.19; also elsewhere on the board
ICE_31: U7.31; also elsewhere on the board
ICE_32: U7.32; also elsewhere on the board
ICE_32MHZOSC: OSC1.3OUT, U7.35GBIN0
ICE_34: U7.34; also elsewhere on the board
ICE_BTN: R22.1, U7.48; also elsewhere on the board
ICE_CDONE: R14.1, U7.7CDONE; also elsewhere on the board
ICE_CRESETB: R9.1, SW8.2, U7.8CRESETB; also elsewhere on the board
ICE_FLASHWPN: R4.1, U10.3WPNIO2; also elsewhere on the board
ICE_HOLDN: U10.7HOLDNIO3; also elsewhere on the board
ICE_LEDB: R2.1, U7.46; also elsewhere on the board
ICE_LEDG: R3.1, U7.45; also elsewhere on the board
ICE_LEDR: R1.1, U7.44GBIN6; also elsewhere on the board
ICE_RGB0: U7.41RGB0; also elsewhere on the board
ICE_RGB1: U7.40RGB1; also elsewhere on the board
ICE_RGB2: U7.39RGB2; also elsewhere on the board
ICE_SCK: U7.15SPISCK, U10.6SCK; also elsewhere on the board
ICE_SDI: U7.14SPISO, U10.5SIIO0; also elsewhere on the board
ICE_SDO: U7.17SPISI, U10.2SOIO1; also elsewhere on the board
ICE_SSB: R37.2, U7.16SPISS, U10.1CSN; also elsewhere on the board
ICE_VCC: C67.1, C68.1, C69.1, C70.1, C71.1, R16.1, U7.5VCC, U7.30VCC
ICE_VCCIO0: C65.1, R36.1, U7.33VCCIO0
ICE_VCCIO1: C63.1, R9.2, R14.2, R35.1, U7.22SPIVCCIO1
ICE_VCCIO2: C62.1, R15.2, U7.1VCCIO2; also elsewhere on the board
ICE_XTALEN: OSC1.1OESTN, R13.1, R41.2, T13.1
unnamed: R1.2, U1.3RED
unnamed: R3.2, U1.2GREEN
unnamed: R2.2, U1.1BLUE
unnamed: C10.1, OSC1.4VCC, R12.1
unnamed: C20.1, R15.1, R22.2, SW7.2
unnamed: R31.2, SW7.S
unnamed: R30.2, SW8.S
unnamed: C2.1, R39.1, U1.4ANODE
NRFICE1: U7.13; also elsewhere on the board
NRFICE2: U7.18; also elsewhere on the board
NRFICE4: U7.10; also elsewhere on the board
NRFICE5: U7.11; also elsewhere on the board
NRFICE6: U7.12; also elsewhere on the board
NRFICE7: U7.25; also elsewhere on the board
NRFICE8: U7.26; also elsewhere on the board
NRFICE9: U7.27; also elsewhere on the board
NRFICE10: U7.28; also elsewhere on the board
PLLVCC: C4.1, C75.1, R91.1, U7.29VCCPLL
UARTRX: U7.37GBIN1; also elsewhere on the board
UARTTX: U7.36; also elsewhere on the board

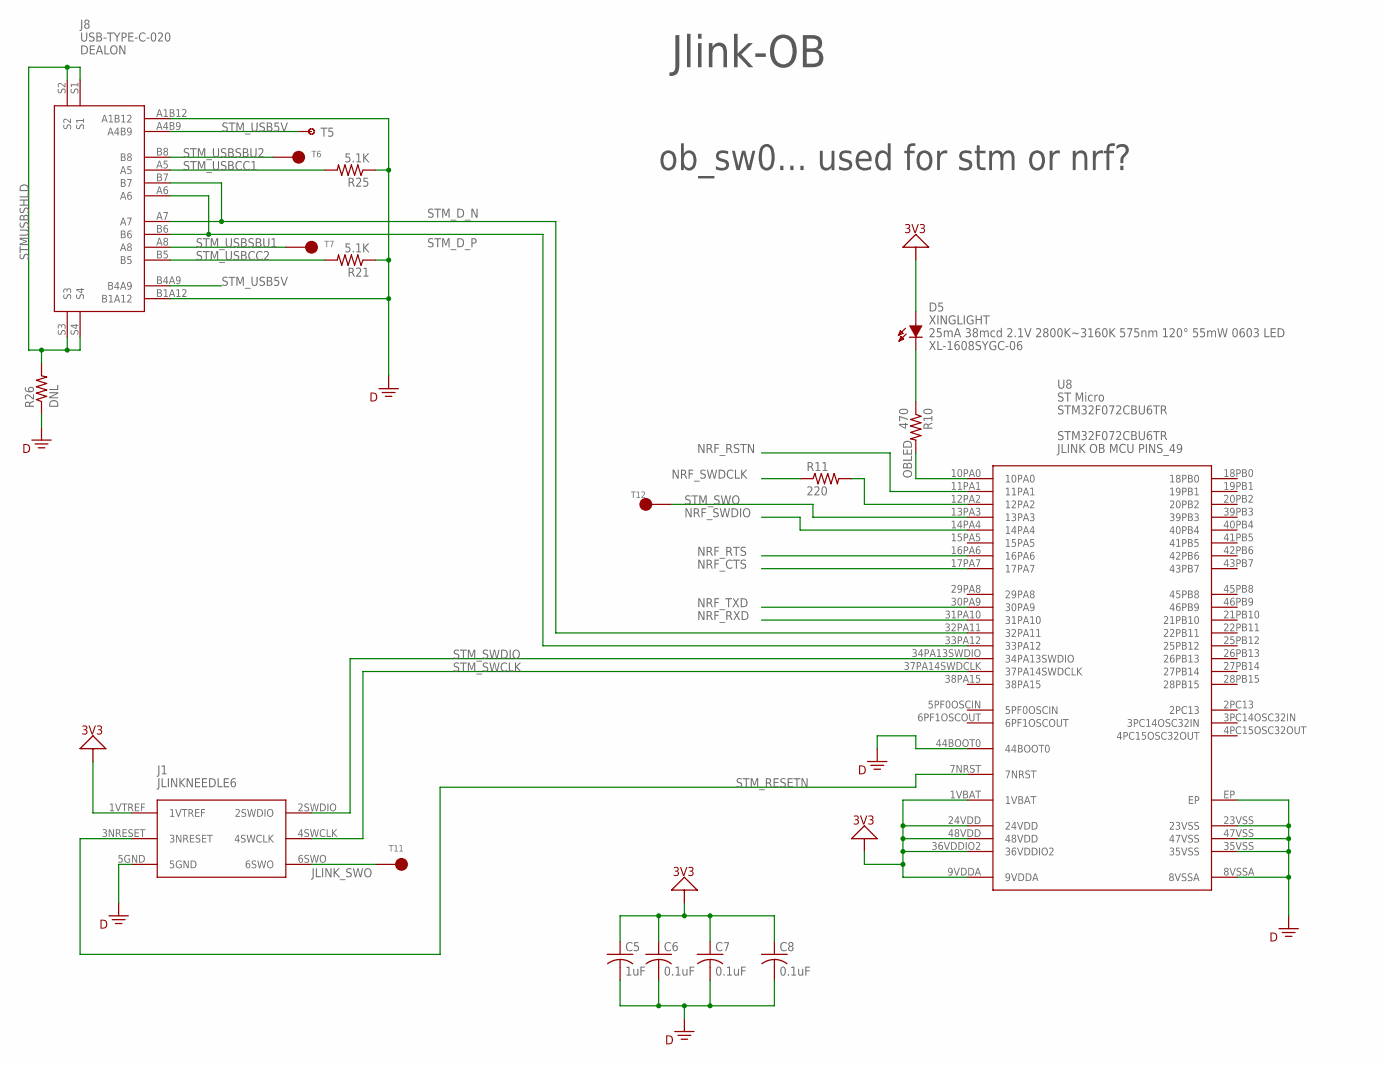
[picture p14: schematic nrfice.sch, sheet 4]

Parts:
C5: 1uF; RCL_C0402; MPN CL05A105KP5NNNC
C6, C7, C8: 0.1uF; RCL_C0402; MPN C0402C104K8RAC7867
D5: XL-1608SYGC-06; MPN XL-1608SYGC-06
J1: JLINKNEEDLE6
J8: USB-TYPE-C-020; MPN USB-TYPE-C-020
R10: 470; RCL_R0402; MPN RC0402FR-07470RL
R11: 220; RCL_R0402; MPN RC0402FR-07220RL
R21, R25: 5.1K; RCL_R0402; MPN RC0402FR-075K1L
R26: DNL; RCL_R0402; MPN RC0402FR-0710KL
T5: MTA1
T6, T7, T11, T12: T
U8: STM32F072CBU6TR; MPN STM32F072CBU6TR

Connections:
3V3: C5.1, C6.1, C7.1, C8.1, D5.A, J1.1VTREF, U8.1VBAT, U8.9VDDA, U8.24VDD, U8.36VDDIO2, U8.48VDD; also elsewhere on the board
DGND: C5.2, C6.2, C7.2, C8.2, J1.5GND, J8.A1B12, J8.B1A12, R21.1, R25.1, R26.1, U8.8VSSA, U8.23VSS, U8.35VSS, U8.44BOOT0, U8.47VSS, U8.EP; also elsewhere on the board
JLINK_SWO: J1.6SWO, T11.T
unnamed: R11.2, U8.12PA2
unnamed: D5.C, R10.1
NRF_CTS: U8.17PA7; also elsewhere on the board
NRF_RSTN: U8.11PA1; also elsewhere on the board
NRF_RTS: U8.16PA6; also elsewhere on the board
NRF_RXD: U8.31PA10; also elsewhere on the board
NRF_SWDCLK: R11.1; also elsewhere on the board
NRF_SWDIO: U8.14PA4; also elsewhere on the board
NRF_TXD: U8.30PA9; also elsewhere on the board
OBLED: R10.2, U8.10PA0
STMUSBSHLD: J8.S1, J8.S2, J8.S3, J8.S4, R26.2
STM_D_N: J8.A7, J8.B7, U8.32PA11
STM_D_P: J8.A6, J8.B6, U8.33PA12
STM_RESETN: J1.3NRESET, U8.7NRST
STM_SWCLK: J1.4SWCLK, U8.37PA14SWDCLK; also elsewhere on the board
STM_SWDIO: J1.2SWDIO, U8.34PA13SWDIO; also elsewhere on the board
STM_SWO: T12.T, U8.13PA3
STM_USB5V: J8.A4B9, J8.B4A9, T5.1; also elsewhere on the board
STM_USBCC1: J8.A5, R25.2
STM_USBCC2: J8.B5, R21.2
STM_USBSBU1: J8.A8, T7.T
STM_USBSBU2: J8.B8, T6.T

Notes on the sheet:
Jlink-OB
ob_sw0... used for stm or nrf?

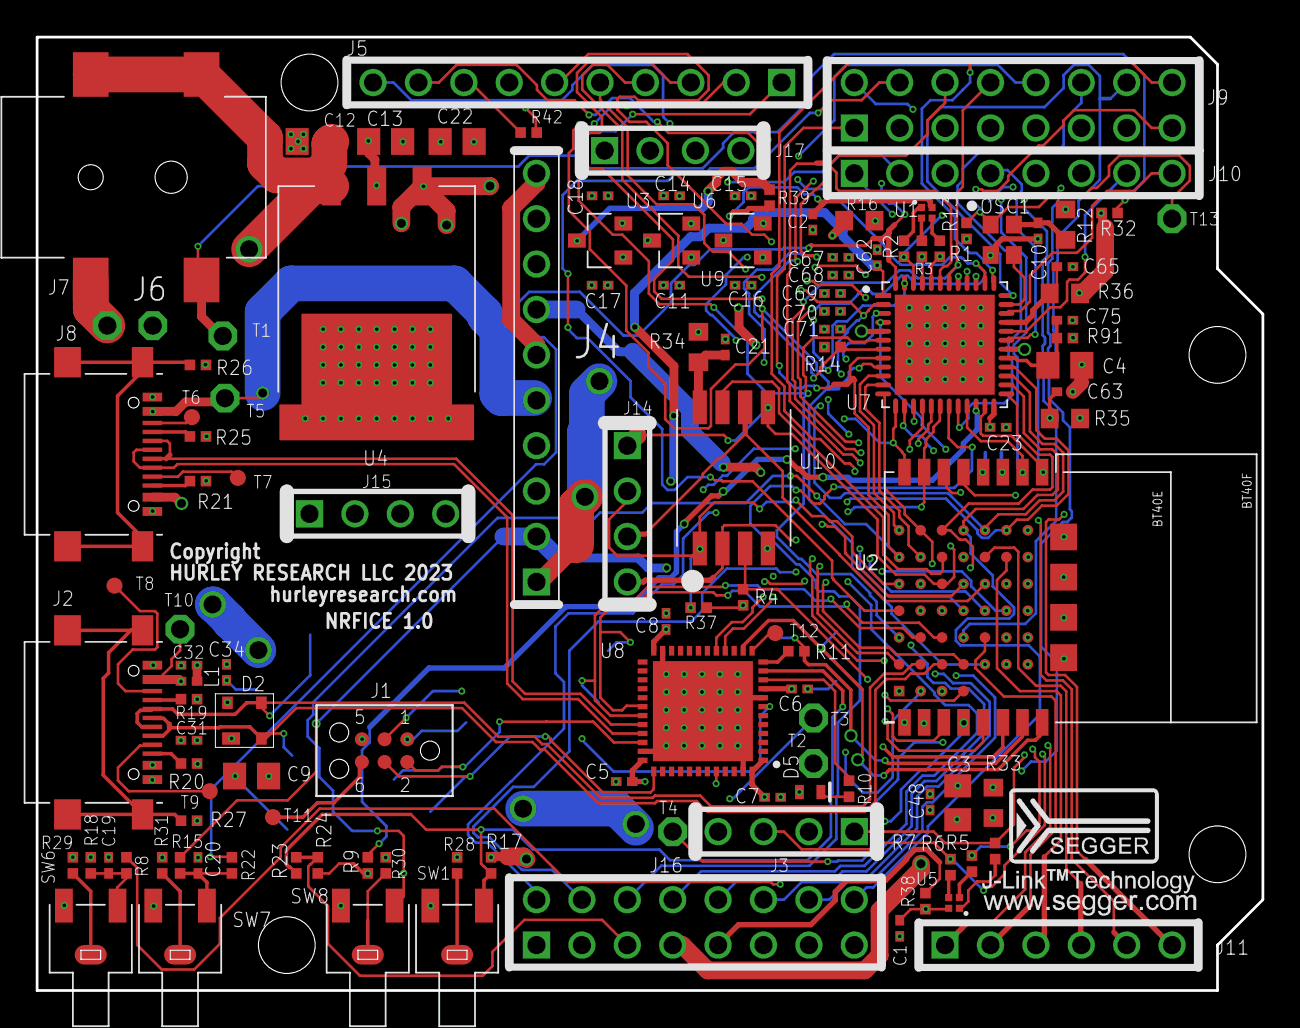
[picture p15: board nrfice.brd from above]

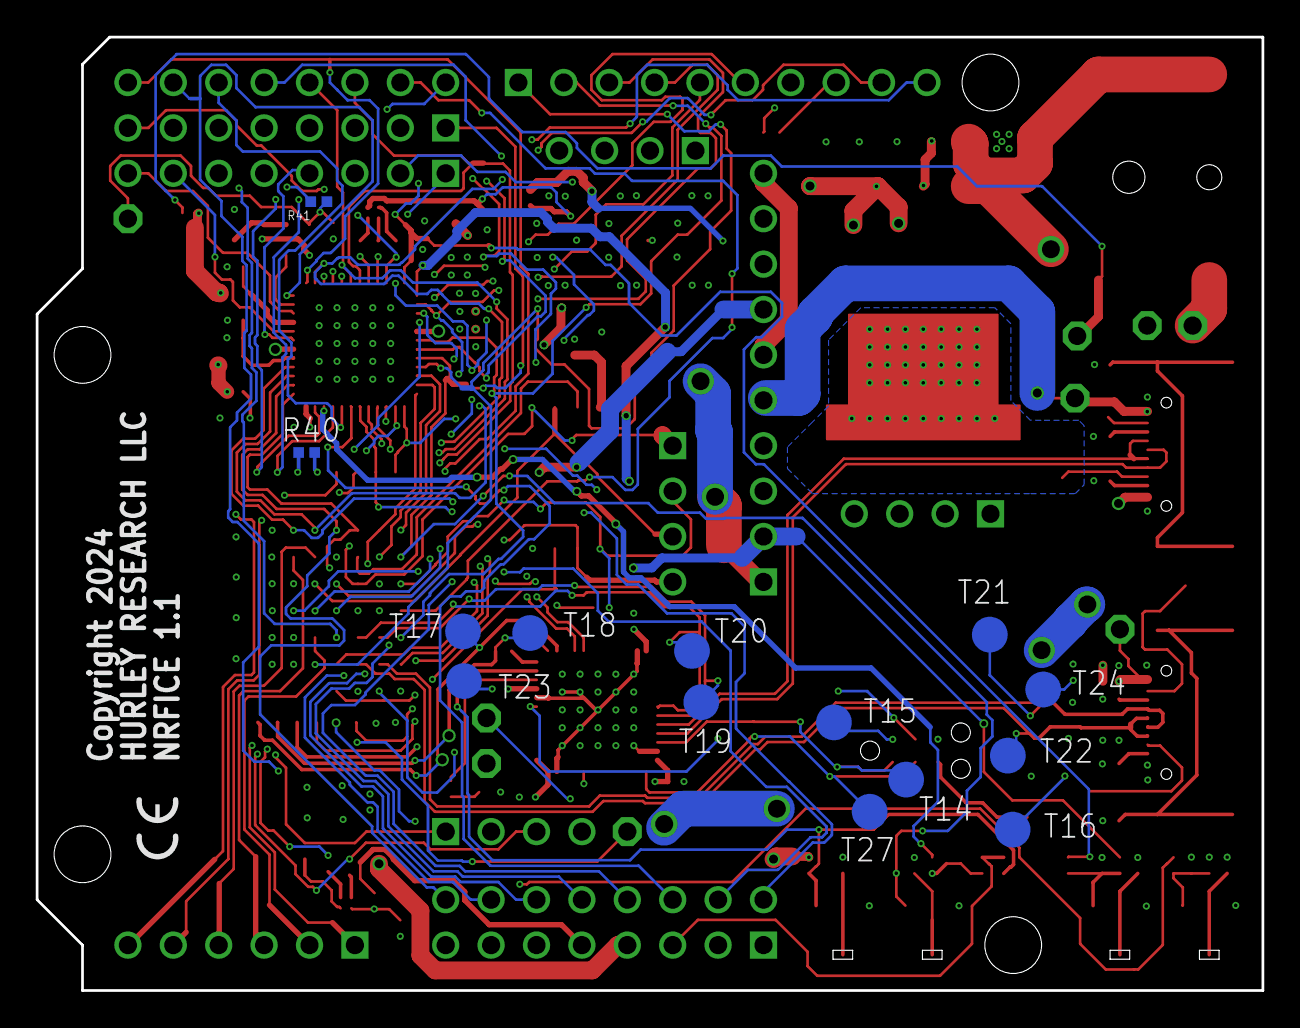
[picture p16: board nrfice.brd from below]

Board: 4 copper layers, 68.6 x 53.3 mm, 137 parts (14 on the bottom side), 126 nets.

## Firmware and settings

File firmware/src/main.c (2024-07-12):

/*
MIT License

Copyright (c) 2024 Hurley Research LLC

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
THE SOFTWARE IS PROVIDED "AS IS", WITHOUT WARRANTY OF ANY KIND, EXPRESS OR
IMPLIED, INCLUDING BUT NOT LIMITED TO THE WARRANTIES OF MERCHANTABILITY,
FITNESS FOR A PARTICULAR PURPOSE AND NONINFRINGEMENT. IN NO EVENT SHALL THE
AUTHORS OR COPYRIGHT HOLDERS BE LIABLE FOR ANY CLAIM, DAMAGES OR OTHER
LIABILITY, WHETHER IN AN ACTION OF CONTRACT, TORT OR OTHERWISE, ARISING FROM,
OUT OF OR IN CONNECTION WITH THE SOFTWARE OR THE USE OR OTHER DEALINGS IN THE
SOFTWARE.
 */

/** @file
 *  @brief Nordic UART Bridge Service (NUS) sample
 */
#include "uart_async_adapter.h"

#include <zephyr/types.h>
#include <zephyr/kernel.h>
#include <zephyr/drivers/uart.h>
#include <zephyr/usb/usb_device.h>

#include <zephyr/device.h>
#include <zephyr/devicetree.h>
#include <soc.h>

#include <zephyr/bluetooth/bluetooth.h>
#include <zephyr/bluetooth/uuid.h>
#include <zephyr/bluetooth/gatt.h>
#include <zephyr/bluetooth/hci.h>

#include <bluetooth/services/nus.h>

#include <dk_buttons_and_leds.h>

#include <zephyr/settings/settings.h>

#include <stdio.h>

#include <zephyr/logging/log.h>

#include "spimflash.h"
#include "utils.h"
#define testdelay k_sleep(K_MSEC(1))
#define LOG_MODULE_NAME peripheral_uart
LOG_MODULE_REGISTER(LOG_MODULE_NAME);

#define STACKSIZE CONFIG_BT_NUS_THREAD_STACK_SIZE
#define PRIORITY 7

#define DEVICE_NAME CONFIG_BT_DEVICE_NAME
#define DEVICE_NAME_LEN (sizeof(DEVICE_NAME) - 1)

static K_SEM_DEFINE(ble_init_ok, 0, 1);

static struct bt_conn *current_conn;
static struct bt_conn *auth_conn;

static const struct bt_data ad[] = {
	BT_DATA_BYTES(BT_DATA_FLAGS, (BT_LE_AD_GENERAL | BT_LE_AD_NO_BREDR)),
	BT_DATA(BT_DATA_NAME_COMPLETE, DEVICE_NAME, DEVICE_NAME_LEN),
};

static const struct bt_data sd[] = {
	BT_DATA_BYTES(BT_DATA_UUID128_ALL, BT_UUID_NUS_VAL),
};

#if CONFIG_BT_NUS_UART_ASYNC_ADAPTER
UART_ASYNC_ADAPTER_INST_DEFINE(async_adapter);
#else
// static const struct device *const async_adapter;
#endif


#define NCOMMANDS 10

#define COMMAND_READ_FLASH_BT 110
#define COMMAND_READ_FLASH_STATUS 111
#define COMMAND_WRITE_FLASH 112
#define COMMAND_ERASE_FLASH 113
#define COMMAND_TEST_FLASH 114
#define COMMAND_HARDRESETICE 115
#define COMMAND_SOFTRESETEICE 116
#define COMMAND_CRESETBLOW 117
#define COMMAND_CRESETBHIGH 118
#define COMMAND_TESTREADFLASH 119
#define COMMAND_TESTWRITEFLASH 127
#define COMMAND_ERASEZERO 131

#define COMMAND_TESTBTSEND 132

#define COMMAND_READ_FLASH_SERIAL 120
#define COMMAND_RAMTEST 121
#define COMMAND_RAMTESTLONG 122

#define COMMAND_SETRGB 210
#define COMMANDLENGTH 128
uint8_t commandBytes[COMMANDLENGTH];

static void connected(struct bt_conn *conn, uint8_t err)
{
	char addr[BT_ADDR_LE_STR_LEN];
	if (err)
	{
		lg("connection failed\n");
		LOG_ERR("Connection failed (err %u)", err);
		return;
	}
	bt_addr_le_to_str(bt_conn_get_dst(conn), addr, sizeof(addr));

	current_conn = bt_conn_ref(conn);

    struct bt_conn_info info;
	bt_conn_get_info(current_conn,&info);
	lgv("set conn val %i\n",info.id);

}

static void disconnected(struct bt_conn *conn, uint8_t reason)
{
	char addr[BT_ADDR_LE_STR_LEN];
	lg("disconnected\n");
	bt_addr_le_to_str(bt_conn_get_dst(conn), addr, sizeof(addr));
	LOG_INF("Disconnected: %s (reason %u)", addr, reason);
	if (auth_conn)
	{
		bt_conn_unref(auth_conn);
		auth_conn = NULL;
	}
	if (current_conn)
	{
		bt_conn_unref(current_conn);
		current_conn = NULL;
	}
}

#ifdef CONFIG_BT_NUS_SECURITY_ENABLED
static void security_changed(struct bt_conn *conn, bt_security_t level,
							 enum bt_security_err err)
{
	char addr[BT_ADDR_LE_STR_LEN];
	bt_addr_le_to_str(bt_conn_get_dst(conn), addr, sizeof(addr));
	if (!err)
	{
		LOG_INF("Security changed: %s level %u", addr, level);
	}
	else
	{
		LOG_WRN("Security failed: %s level %u err %d", addr,
				level, err);
	}
}
#endif

BT_CONN_CB_DEFINE(conn_callbacks) = {
	.connected = connected,
	.disconnected = disconnected,
#ifdef CONFIG_BT_NUS_SECURITY_ENABLED
	.security_changed = security_changed,
#endif
};

#if defined(CONFIG_BT_NUS_SECURITY_ENABLED)
static void auth_passkey_display(struct bt_conn *conn, unsigned int passkey)
{
	char addr[BT_ADDR_LE_STR_LEN];
	bt_addr_le_to_str(bt_conn_get_dst(conn), addr, sizeof(addr));
	LOG_INF("Passkey for %s: %06u", addr, passkey);
}

static void auth_passkey_confirm(struct bt_conn *conn, unsigned int passkey)
{
	char addr[BT_ADDR_LE_STR_LEN];
	auth_conn = bt_conn_ref(conn);
	bt_addr_le_to_str(bt_conn_get_dst(conn), addr, sizeof(addr));
	LOG_INF("Passkey for %s: %06u", addr, passkey);
	LOG_INF("Press Button 1 to confirm, Button 2 to reject.");
}

static void auth_cancel(struct bt_conn *conn)
{
	char addr[BT_ADDR_LE_STR_LEN];
	bt_addr_le_to_str(bt_conn_get_dst(conn), addr, sizeof(addr));
	LOG_INF("Pairing cancelled: %s", addr);
}

static void pairing_complete(struct bt_conn *conn, bool bonded)
{
	char addr[BT_ADDR_LE_STR_LEN];
	bt_addr_le_to_str(bt_conn_get_dst(conn), addr, sizeof(addr));
	LOG_INF("Pairing completed: %s, bonded: %d", addr, bonded);
}

static void pairing_failed(struct bt_conn *conn, enum bt_security_err reason)
{
	char addr[BT_ADDR_LE_STR_LEN];
	bt_addr_le_to_str(bt_conn_get_dst(conn), addr, sizeof(addr));
	LOG_INF("Pairing failed conn: %s, reason %d", addr, reason);
}

static struct bt_conn_auth_cb conn_auth_callbacks = {
	.passkey_display = auth_passkey_display,
	.passkey_confirm = auth_passkey_confirm,
	.cancel = auth_cancel,
};

static struct bt_conn_auth_info_cb conn_auth_info_callbacks = {
	.pairing_complete = pairing_complete,
	.pairing_failed = pairing_failed};
#else
static struct bt_conn_auth_cb conn_auth_callbacks;
static struct bt_conn_auth_info_cb conn_auth_info_callbacks;
#endif

///////////////////////////////////////////////////////////////////////////////////////////////////
////////////////////////////////////////////////////////////////////////////////////////////////////








uint8_t flashTestBuf[128];
uint8_t readBufBT[20];
uint8_t sendBufBT[20];

uint32_t waitCount = 0;

uint32_t flashReadStartAddress = 0;
uint32_t flashReadLength = 0;
uint32_t flashReadCurrentAddress = 0;
uint32_t flashReadSessionID = 0;
void flashGPIOICE()
{
	gpioConfigInputNoPull(ICE_SCK); 
	gpioConfigInputNoPull(ICE_SSB); 
									
	gpioConfigInputNoPull(ICE_SDI);
	gpioConfigInputNoPull(ICE_SDO);
}

void flashGPIONRF()
{
	gpioConfigOutputDrive(ICE_SCK, DRIVEH0H1); 
	pinClear(ICE_SSB);
	gpioConfigOutputDrive(ICE_SSB, DRIVEH0H1);
	pinSet(ICE_SSB);

	gpioConfigOutputDrive(ICE_SDI, DRIVEH0H1);
	pinClear(ICE_SDI);

	gpioConfigInputNoPull(ICE_SDO);
}

void commandReadFlashBT(uint8_t *data)
{
	pinClear(ICE_CRESETB);
	flashReadStartAddress = unpack32(data, 4);
	flashReadLength = unpack32(data, 8);
	flashReadSessionID = unpack32(data, 12);
	flashReadCurrentAddress = flashReadStartAddress;
	lgv("readFlashBT %d\n", flashReadSessionID);
}
char hexChars[] = {
	'0',
	'1',
	'2',
	'3',
	'4',
	'5',
	'6',
	'7',
	'8',
	'9',
	'A',
	'B',
	'C',
	'D',
	'E',
	'F',
};
void bytesToHexString(uint8_t *bytes, char *str, int len)
{
	for (int i = 0; i < len; i++)
	{
		uint8_t b = bytes[i];
		str[i * 2] = hexChars[(b >> 4) & 0x0f];
		str[i * 2 + 1] = hexChars[b & 0x0f];
	}
}
void commandReadFlashStatus()
{
	pinClear(ICE_CRESETB);

	uint8_t status = flashReadStatus();
	lgv("yayflash status %d\n", status);

}
uint32_t maxWaitCount = 0;
uint8_t readCheckBuf[16];
void commandWriteFlash(uint8_t *data, uint8_t len)
{
	pinClear(ICE_CRESETB);

	uint8_t status = flashReadStatus();

	uint32_t startAddress = unpack24(data, 1);

	if (startAddress % 0x1000 == 0)
	{
	}

	flashWriteEnable();
	flashProgram(data, startAddress, len);

	waitCount = 0;
	status = flashReadStatus();
	while (status > 0)
	{
		status = flashReadStatus();
		waitCount++;
	}
	if (waitCount > maxWaitCount)
	{
		maxWaitCount = waitCount;
	}

	flashWriteDisable();
	flashRead(readCheckBuf, startAddress, len);
	uint32_t badX = 0;
	uint8_t allGood = 1;
	for (uint8_t x = 0; x < len; x++)
	{
		if (readCheckBuf[x] != data[x + 4])
		{
			allGood = 0;
			badX = x;
			x = len;
		}
	}
	if (allGood == 0)
	{

		lgv("allgood zero: \n", badX);

		flashWriteEnable();
		flashProgram(data, startAddress, len);

		flashWriteDisable();
		flashRead(readCheckBuf, startAddress, len);

		uint8_t allGoodAgain = 1;
		for (uint8_t x = 0; x < len; x++)
		{
			if (readCheckBuf[x] != data[x + 4])
			{
				allGoodAgain = 0;
				badX = x;
				x = len;
			}
		}
		if (allGoodAgain == 0)
		{

			lgv("allgood zero again: %d\n", badX);
		}
	}

	status = flashReadStatus();
	if (startAddress % 0x1000 == 0)
	{
	}
}

void commandEraseFlash(uint8_t *data)
{
	pinClear(ICE_CRESETB);

	uint32_t addr = unpack24(data, 1);

	uint8_t status = flashReadStatus();
	lgv("erase %d", status);
	waitCount = 0;
	flashWriteEnable();
	flashEraseSector(addr);

	status = flashReadStatus();

}

void commandEraseZero()
{
	pinClear(ICE_CRESETB);

	flashWriteEnable();
	flashEraseSector(0);
}

uint32_t insideFlashReadSession = 0;
void flashReadSession()
{

	insideFlashReadSession = 1;
	if (flashReadCurrentAddress < flashReadLength + flashReadStartAddress)
	{
		lg("readFlashSession");
		uint8_t status = flashReadStatus();
		if (status != 0)
		{

			lgv("abort %d\n", status);
			flashReadCurrentAddress = flashReadLength + flashReadStartAddress;
			insideFlashReadSession = 0;
			return;
		}
		flashRead(readBufBT, flashReadCurrentAddress, 16);
		for (uint8_t x = 0; x < 16; x++)
		{
			sendBufBT[x + 4] = readBufBT[x];
		}
		sendBufBT[0] = COMMAND_READ_FLASH_BT;
		pack24(flashReadCurrentAddress, sendBufBT, 1);

		int wth = bt_nus_send(current_conn, sendBufBT, 20);
		if (wth != 0)
		{
			lgv("prblm session %i\n", wth);
			flashReadCurrentAddress = flashReadLength + flashReadStartAddress;
		}
		else
		{
			flashReadCurrentAddress += 16;
		}
	}
	insideFlashReadSession = 0;
}

void testFlashRead(void)
{

	lg("testFlashRead");
	uint8_t status = flashReadStatus();
	lgv("test status read: %i\n", status);

	flashRead(readBufBT, 0, 16);
	for (uint8_t x = 0; x < 16; x++)
	{
		testdelay;
		lgv("readbuf %i\n", readBufBT[x]);
	}
}

void testBTSend(void)
{


	struct bt_conn_info info;
	bt_conn_get_info(current_conn,&info);
	lgv("sendID %i\n", info.id);

	for (uint8_t x = 0; x < 20; x++)
	{
		sendBufBT[x] = x;
	}
	sendBufBT[0] = COMMAND_READ_FLASH_BT;

	int wth = bt_nus_send(current_conn, sendBufBT, 20);

	if (wth != 0)
	{
		lgv("fprobnus %i\n", wth);
	}
	else
	{
		lgv("good nus %i\n", wth);
	}
}

void testFlashWrite(void)
{

	lg("testFlashWrite");
	uint8_t status = flashReadStatus();
	lgv("testFlashWrite: %i\n", status);
	for (int x = 0; x < 64; x++)
	{
		flashTestBuf[x] = x;
		flashWriteEnable();
	}
	flashProgram(flashTestBuf, 0, 64);
	lg("after flash program");
}

#define testdelay k_sleep(K_MSEC(1))
void writeEBRByte(uint8_t byte) {
    for (uint8_t b = 0; b < 8; b++) {
        if (((byte >> (7 - b)) & 0x01) == 0x01) {
            pinSet(ICEAPP_SPIMOSI);
        } else {
            pinClear(ICEAPP_SPIMOSI);
        }
        testdelay;
        pinSet(ICEAPP_SPICLK);
        testdelay;
        pinClear(ICEAPP_SPICLK);
    }
}
void writeEBR(uint8_t addr, uint16_t val)
{
	testdelay;
	pinClear(ICEAPP_SPICLK);
	pinClear(ICEAPP_SPIMOSI);
	pinClear(ICEAPP_SPICSN);
	testdelay;
	writeEBRByte(0x10); 
	testdelay;
	writeEBRByte(addr);
	testdelay;
	writeEBRByte((val >> 8) & 0xff);
	testdelay;
	writeEBRByte(val & 0xff);
	testdelay;

	pinSet(ICEAPP_SPICSN);
	pinClear(ICEAPP_SPICLK);
	pinClear(ICEAPP_SPIMOSI);
}


void writeFPGARGB(uint8_t addr, uint8_t val)
{
	testdelay;
	pinClear(ICEAPP_SPICLK);
	pinClear(ICEAPP_SPIMOSI);
	pinClear(ICEAPP_SPICSN);
	testdelay;
	writeEBRByte(0x12 + addr); 
	testdelay;
	writeEBRByte(addr);
	testdelay;
	writeEBRByte(0);
	testdelay;
	writeEBRByte(val & 0xff);
	testdelay;

	pinSet(ICEAPP_SPICSN);
	pinClear(ICEAPP_SPICLK);
	pinClear(ICEAPP_SPIMOSI);
	testdelay;
}



void setRGB(uint8_t *data) {
    uint8_t r = data[1];
    uint8_t g = data[2];
    uint8_t b = data[3];

    writeFPGARGB(0,r);
    writeFPGARGB(1,g);
    writeFPGARGB(2,b);


}


void processCommand(uint8_t payloadSize)
{

	uint8_t command = commandBytes[0];
      lgv("cmd %i\n", command);
	if (command == COMMAND_READ_FLASH_BT)
	{
		commandReadFlashBT(commandBytes);
	}
	else if (command == COMMAND_READ_FLASH_STATUS)
	{

		commandReadFlashStatus();
	}
	else if (command == COMMAND_READ_FLASH_SERIAL)
	{
		// commandReadFlashSerial(commandBytes);
	}
	else if (command == COMMAND_ERASEZERO)
	{
		commandEraseZero();
	}
	else if (command == COMMAND_RAMTEST)
	{
		// uint8_t ramAddr = commandBytes[1];
		// uint16_t ramData = unpack16(commandBytes, 2);
		// commandRamTest(ramAddr, ramData);
	}
	else if (command == COMMAND_RAMTESTLONG)
	{
		// commandRamTestLong();
	}
	else if (command == COMMAND_WRITE_FLASH)
	{
		commandWriteFlash(commandBytes, payloadSize);
	}
	else if (command == COMMAND_ERASE_FLASH)
	{
		commandEraseFlash(commandBytes);
	}
	else if (command == COMMAND_TEST_FLASH)
	{
		pinClear(ICE_CRESETB);
		uint8_t status = flashReadStatus();
		flashWriteEnable();
		status = flashReadStatus();
		flashWriteDisable();
		status = flashReadStatus();
	}
	else if (command == COMMAND_HARDRESETICE)
	{
		pinClear(NRF_LEDR);
		flashGPIOICE();
		k_sleep(K_MSEC(100));
		pinSet(ICE_CRESETB);
		k_sleep(K_MSEC(100));
		pinClear(ICE_CRESETB);
		k_sleep(K_MSEC(100));
		pinSet(ICE_CRESETB);
		pinSet(NRF_LEDR);
	
	}
	else if (command == COMMAND_SOFTRESETEICE)
	{

	


		pinClear(NRF_LEDG);
		pinClear(ICESOFTRESET);
		k_sleep(K_MSEC(100));
		pinSet(ICESOFTRESET);

		k_sleep(K_MSEC(100));
		pinClear(ICESOFTRESET);
		pinSet(NRF_LEDG);
	}
	else if (command == COMMAND_CRESETBLOW)
	{
		pinClear(ICE_CRESETB);
	}
	else if (command == COMMAND_CRESETBHIGH)
	{
		pinSet(ICE_CRESETB);
	}
	else if (command == COMMAND_TESTBTSEND)
	{
		testBTSend();
	}
	else if (command == COMMAND_TESTREADFLASH)
	{

		testFlashRead();

	}
	else if (command == COMMAND_TESTWRITEFLASH)
	{

		testFlashWrite();

	}
	else if (command == COMMAND_SETRGB)
	{
		setRGB(commandBytes);
	}
}
////////////////////////////////////////////////////////////

static void bt_receive_cb(struct bt_conn *conn, const uint8_t *const data, uint16_t len)
{

	char addr[BT_ADDR_LE_STR_LEN] = {0};



	bt_addr_le_to_str(bt_conn_get_dst(conn), addr, ARRAY_SIZE(addr));
	for (uint8_t x = 0; x < 20; x++)
	{
		commandBytes[x] = data[x];
	}
	processCommand(16);

}

static struct bt_nus_cb nus_cb = {
	.received = bt_receive_cb,
};

void error(void)
{
	while (true)
	{
		k_sleep(K_MSEC(1000));
	}
}

uint32_t hbi = 0;
void heartBeat(void)
{
	if (hbi % 2 == 0)
	{
		pinClear(NRF_LEDR);
	}
	else
	{
		pinSet(NRF_LEDR);
	}
	hbi++;

	if (insideFlashReadSession == 0)
	{
		flashReadSession();
	}
}

int main(void)
{
	
	int err = 0;

	gpioConfigOutputSet(ICEAPP_SPICSN);
	gpioConfigOutputClear(ICEAPP_SPICLK);
	gpioConfigOutputClear(ICEAPP_SPIMOSI);
	gpioConfigInputNoPull(ICEAPP_SPIMISO);
	gpioConfigOutputClear(ICESOFTRESET);
	gpioConfigOutputClear(ICE_CRESETB);

	gpioConfigOutputSet(NRF_LEDR);
	gpioConfigOutputSet(NRF_LEDG);
	gpioConfigOutputSet(NRF_LEDB);
	setupSeggerUART();
	lg("top of main");
	if (IS_ENABLED(CONFIG_BT_NUS_SECURITY_ENABLED))
	{
		err = bt_conn_auth_cb_register(&conn_auth_callbacks);
		if (err)
		{
			printk("Failed to register authorization callbacks.\n");
			return 0;
		}

		err = bt_conn_auth_info_cb_register(&conn_auth_info_callbacks);
		if (err)
		{
			printk("Failed to register authorization info callbacks.\n");
			return 0;
		}
	}
	err = bt_enable(NULL);
	if (err)
	{
		error();
	}
	LOG_INF("Bluetooth initialized");
	k_sem_give(&ble_init_ok);
	if (IS_ENABLED(CONFIG_SETTINGS))
	{
		settings_load();
	}
	err = bt_nus_init(&nus_cb);
	if (err)
	{
		LOG_ERR("Failed to initialize UART service (err: %d)", err);
		return 0;
	}
	err = bt_le_adv_start(BT_LE_ADV_CONN, ad, ARRAY_SIZE(ad), sd, ARRAY_SIZE(sd));
	if (err)
	{
		LOG_ERR("Advertising failed to start (err %d)", err);
		return 0;
	}
	spimFlashInit();

	for (;;)
	{

		k_sleep(K_MSEC(100));
		heartBeat();
	}
}

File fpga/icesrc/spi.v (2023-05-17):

module spi (
	clock,
	reset,
	clk,

	csn,
	mosi,
	ramReadData,

	debug4,
	miso,
	ramAddr,
	ramCLK,
	ramCLKEn,
	ramWriteData,
	ramWriteEn,
	stateDebug,
	pwmRegs
);


input  clk;
input  clock;
input  csn;
input  mosi;
input [15:0] ramReadData;
input  reset;

output [3:0] debug4;
output  miso;
output [7:0] ramAddr;
output  ramCLK;
output  ramCLKEn;
output [15:0] ramWriteData;
output  ramWriteEn;
output [19:0] stateDebug;
output [47:0] pwmRegs;


// ------------------------------
//        Define States          
// ------------------------------

parameter [4:0] CLKHIGH = 5'b0001;
parameter [4:0] CLKHIGHREAD = 5'b1010;
parameter [4:0] CLKHIGHREADLOOP = 5'b1110;
parameter [4:0] CLKLOW = 5'b0010;
parameter [4:0] CLKLOWREAD = 5'b1100;
parameter [4:0] CSNHIGH = 5'b0000;
parameter [4:0] CSNLOW = 5'b1000;
parameter [4:0] COMMAND = 5'b0110;
parameter [4:0] LASTBIT = 5'b0101;
parameter [4:0] LASTBITCLKHIGH = 5'b10010;
parameter [4:0] LASTBITCLKLOW = 5'b10011;
parameter [4:0] LATCHBIT = 5'b0100;
parameter [4:0] LATCHREADWORD = 5'b1011;
parameter [4:0] READLOWERCLK = 5'b10000;
parameter [4:0] READRAISECLK = 5'b1111;
parameter [4:0] READRAISECLK2 = 5'b10001;
parameter [4:0] SHIFT = 5'b0011;
parameter [4:0] SHIFTREAD = 5'b1101;
parameter [4:0] WRITEPWMREG0 = 5'b10100;
parameter [4:0] WRITEPWMREG1 = 5'b10101;
parameter [4:0] WRITEPWMREG2 = 5'b10110;
parameter [4:0] WRITERAM = 5'b0111;
parameter [4:0] WRITERAMSTORE = 5'b1001;

parameter  newParameter = 1'b0;



// ------------------------------
//        Definitions          
// ------------------------------


wire  clk;
wire  clock;
wire  csn;
wire [3:0] debug4;
wire  miso;
wire  mosi;
wire [7:0] ramAddr;
wire  ramCLK;
wire  ramCLKEn;
wire [15:0] ramReadData;
wire [15:0] ramWriteData;
wire  ramWriteEn;
wire  reset;
wire [19:0] stateDebug;

reg [7:0] bitCount;
reg  clkBuf;
reg  csnBuf;
reg  mosiBuf;
reg [47:0] pwmRegs;
reg [7:0] ramAddrReg;
reg  ramCLKEnReg;
reg  ramCLKReg;
reg  ramWriteEnReg;
reg  readMode;
reg [15:0] readWord;
reg [31:0] spiInWord;

reg [22:0] state;
reg [22:0] next;
// ------------------------------
//       Common Code, not used         
// ------------------------------


// ------------------------------
//       Code Block         
// ------------------------------
assign ramCLK = ramCLKReg;
assign ramWriteEn = ramWriteEnReg;
assign ramAddr[7:0] = readMode == 1'b0 ? spiInWord[23:16] : spiInWord[8:1];
assign ramWriteData[15:0] = spiInWord[15:0];
assign miso = readWord[15];
assign stateDebug[19:0] = state[19:0];
assign debug4[3:0] = spiInWord[3:0];
assign ramCLKEn = ramCLKEnReg;


// ------------------------------
//       Input Buffering         
// ------------------------------



always @ (posedge clock or posedge reset) begin 
	if (reset) begin
		clkBuf <= 1'b0;
		csnBuf <= 1'b1;
		mosiBuf <= 1'b0;
	end
	else begin
		clkBuf <= clk;
		csnBuf <= csn;
		mosiBuf <= mosi;
	end
end


// ------------------------------
//   State Switching Block       
// ------------------------------


always @ (posedge clock or posedge reset) begin
	if (reset)	begin
            state <= 23'b0;
            state[CSNHIGH] <= 1'b1;
	end
	else state <= next;
end



// ------------------------------
//          Input Block         
// ------------------------------


always @ ( state , bitCount , clkBuf , csnBuf , readMode , spiInWord) begin
	next = 23'b0;
	case (1'b1)
		state[CLKHIGH]  :  begin
			if( readMode == 1'b1 )
				next[CLKHIGHREAD] = 1'b1;
			else if( clkBuf == 1'b0 && readMode == 1'b0 )
				next[CLKLOW] = 1'b1;
			else if( csnBuf == 1'b1 )
				next[CSNHIGH] = 1'b1;
			else 
				next[CLKHIGH] = 1'b1;
		end
		state[CLKHIGHREAD]  :  begin
			next[READRAISECLK] = 1'b1;
		end
		state[CLKHIGHREADLOOP]  :  begin
			if( clkBuf == 1'b0 )
				next[SHIFTREAD] = 1'b1;
			else 
				next[CLKHIGHREADLOOP] = 1'b1;
		end
		state[CLKLOW]  :  begin
			if( csnBuf == 1'b1 )
				next[CSNHIGH] = 1'b1;
			else if( clkBuf == 1'b1 )
				next[SHIFT] = 1'b1;
			else 
				next[CLKLOW] = 1'b1;
		end
		state[CLKLOWREAD]  :  begin
			if( clkBuf == 1'b1 )
				next[CLKHIGHREADLOOP] = 1'b1;
			else if( csnBuf == 1'b1 )
				next[CSNHIGH] = 1'b1;
			else if( bitCount[7:0] == 8'h10 )
				next[CSNLOW] = 1'b1;
			else 
				next[CLKLOWREAD] = 1'b1;
		end
		state[CSNHIGH]  :  begin
			if( csnBuf == 1'b0 )
				next[CLKHIGH] = 1'b1;
			else 
				next[CSNHIGH] = 1'b1;
		end
		state[CSNLOW]  :  begin
			if( csnBuf == 1'b1 )
				next[CSNHIGH] = 1'b1;
			else 
				next[CSNLOW] = 1'b1;
		end
		state[COMMAND]  :  begin
			if( csnBuf == 1'b1 && spiInWord[31:24] != 8'h10 )
				next[CSNHIGH] = 1'b1;
			else if( spiInWord[31:24] != 8'h10 && spiInWord[31:24] != 8'h11 && spiInWord[31:24] != 8'h12 && spiInWord[31:24] != 8'h13 && spiInWord[31:24] != 8'h14 && clkBuf == 1'b1 )
				next[CSNLOW] = 1'b1;
			else if( spiInWord[31:24] == 8'h12 )
				next[WRITEPWMREG0] = 1'b1;
			else if( spiInWord[31:24] == 8'h13 )
				next[WRITEPWMREG1] = 1'b1;
			else if( spiInWord[31:24] == 8'h14 )
				next[WRITEPWMREG2] = 1'b1;
			else if( spiInWord[31:24] == 8'h10 )
				next[WRITERAM] = 1'b1;
			else 
				next[COMMAND] = 1'b1;
		end
		state[LASTBIT]  :  begin
			if( clkBuf == 1'b0 )
				next[COMMAND] = 1'b1;
			else 
				next[LASTBIT] = 1'b1;
		end
		state[LASTBITCLKHIGH]  :  begin
			if( clkBuf == 1'b0 )
				next[LASTBITCLKLOW] = 1'b1;
			else 
				next[LASTBITCLKHIGH] = 1'b1;
		end
		state[LASTBITCLKLOW]  :  begin
			if( clkBuf == 1'b1 )
				next[LASTBIT] = 1'b1;
			else 
				next[LASTBITCLKLOW] = 1'b1;
		end
		state[LATCHBIT]  :  begin
			if( bitCount == 8'h1F )
				next[LASTBITCLKHIGH] = 1'b1;
			else 
				next[CLKHIGH] = 1'b1;
		end
		state[LATCHREADWORD]  :  begin
			if( clkBuf == 1'b0 )
				next[CLKLOWREAD] = 1'b1;
			else 
				next[LATCHREADWORD] = 1'b1;
		end
		state[READLOWERCLK]  :  begin
			next[READRAISECLK2] = 1'b1;
		end
		state[READRAISECLK]  :  begin
			next[READLOWERCLK] = 1'b1;
		end
		state[READRAISECLK2]  :  begin
			next[LATCHREADWORD] = 1'b1;
		end
		state[SHIFT]  :  begin
			next[LATCHBIT] = 1'b1;
		end
		state[SHIFTREAD]  :  begin
			next[CLKLOWREAD] = 1'b1;
		end
		state[WRITEPWMREG0]  :  begin
			next[CSNLOW] = 1'b1;
		end
		state[WRITEPWMREG1]  :  begin
			next[CSNLOW] = 1'b1;
		end
		state[WRITEPWMREG2]  :  begin
			next[CSNLOW] = 1'b1;
		end
		state[WRITERAM]  :  begin
			next[WRITERAMSTORE] = 1'b1;
		end
		state[WRITERAMSTORE]  :  begin
			next[CSNLOW] = 1'b1;
		end
	endcase
end      // end of input block


// ------------------------------
//         Output Block          
// ------------------------------
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

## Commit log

2023-05-17 Initial project load to github
    [BLEFPGABOM190722.xlsx, NRFICE04_impl_1_vo.sdf, app_bar_main.xml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]
2024-05-08 update to gerber files to reflect the final design as shipped to the board house.
    [Document.gbr, copper_bottom_l4.gbr, copper_inner_l2.gbr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]
2024-07-12 Updates to the android app, cleaned up hardware files, and update to firmware.
    [nrfice.brd, nrfice.sch]

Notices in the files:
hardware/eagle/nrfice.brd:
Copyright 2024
